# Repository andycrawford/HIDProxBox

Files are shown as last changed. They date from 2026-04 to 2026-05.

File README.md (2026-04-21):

# HIDProxBox

A 4-port Bluetooth/USB HID KVM proxy built on a Raspberry Pi and four CH552T microcontrollers. HIDProxBox sits between your input devices (a physical USB keyboard or a Bluetooth keyboard) and up to four computers, letting you switch between hosts instantly with a button press — no software installation required on any of the target computers.

---

## What It Does

- **Switch between 4 computers** with dedicated selector buttons — all computers stay USB-connected at all times
- **Accept input from a physical USB keyboard** plugged into the Pi, or from **any Bluetooth keyboard**
- **Toggle keyboard input source** (USB ↔ BT) with a single button
- **Output via USB** (the Pi talks to each computer through an individual CH552T HID device) **or via Bluetooth** (the Pi presents itself as a wireless keyboard directly to the selected computer)
- **Hold a button to pair** — one hold gesture pairs an upstream BT keyboard; another pairs the Pi itself as a BT keyboard to the active computer
- **LED feedback** — six indicator LEDs show which computer is active, which input source is live, and which output mode is in use
- **Web control panel** — a built-in HTTP server at `http://<pi-ip>:8080` lets you switch computers and toggle modes from any browser on your network
- **Local touchscreen display** — an optional tkinter GUI (`display.py`) runs on a Pi-attached touchscreen, mirroring the web panel with one-tap computer switching and a ZSA Keymapp launcher

---

## Table of Contents

1. [Architecture](#architecture)
2. [Hardware Bill of Materials](#hardware-bill-of-materials)
3. [Assembly & Wiring](#assembly--wiring)
   - [Overview diagram](#overview-diagram)
   - [GPIO buttons](#gpio-buttons-active-low)
   - [GPIO LEDs](#gpio-leds-active-high)
   - [CH552T units](#ch552t-units-one-per-computer)
4. [Software Installation](#software-installation)
5. [CH552T Firmware](#ch552t-firmware)
6. [Configuration](#configuration)
7. [Running the Daemon](#running-the-daemon)
8. [Web Control Panel](#web-control-panel)
   - [Paste Text Entry](#paste-text-entry)
9. [Local Touchscreen Display](#local-touchscreen-display)
10. [Operation](#operation)
11. [HID Macros](#hid-macros)
12. [Troubleshooting](#troubleshooting)
13. [Project Structure](#project-structure)
14. [Contributing](#contributing)
15. [License](#license)

---

## Architecture

```
┌─────────────────────────────────────────────────────────────────┐
│                        Raspberry Pi                             │
│                                                                 │
│  ┌────────────┐   ┌───────────┐   ┌──────────────────────────┐ │
│  │ usb_kbd.py │   │bt_listener│   │      gpio_watcher.py     │ │
│  │ (evdev)    │   │   .py     │   │ 4× computer select btns  │ │
│  │ USB kbd in │   │ BT kbd in │   │ BT-input btn (s/l press) │ │
│  └─────┬──────┘   └─────┬─────┘   │ BT-output btn(s/l press)│ │
│        │  source="usb"  │  source="bt"   └──────┬───────────┘ │
│        └────────────────┴────────────────────────┤             │
│                                                   ▼             │
│                              ┌────────────────────────────┐    │
│                              │         router.py          │    │
│                              │  active_computer : 1–4     │    │
│                              │  input_mode : usb | bt     │    │
│                              │  output_mode: usb | bt     │    │
│                              └──────────┬─────────────────┘    │
│                                         │                       │
│                    ┌────────────────────┴──────────────────┐   │
│                    ▼  output_mode=usb                       ▼   │
│          ┌─────────────────┐                  ┌─────────────────┐│
│          │  hid_writer.py  │                  │  bt_output.py   ││
│          │ 4× serial ports │                  │ Pi as BT HID    ││
│          └──┬──┬──┬──┬─────┘                  │ keyboard device ││
│             │  │  │  │                         └────────┬────────┘│
└─────────────┼──┼──┼──┼──────────────────────────────────┼────────┘
              │  │  │  │  /dev/ttyUSB0–3                   │ Bluetooth
       ┌──────┘  │  │  └──────┐                            │
       ▼         ▼  ▼         ▼                            ▼
  ┌────────┐ ┌──────┐ ┌──────┐ ┌────────┐        (selected computer)
  │CH552T 1│ │  #2  │ │  #3  │ │CH552T 4│
  │USB HID │ │      │ │      │ │USB HID │
  └───┬────┘ └──┬───┘ └──┬───┘ └───┬────┘
      │         │         │         │  USB cables (always plugged in)
      ▼         ▼         ▼         ▼
  Computer1  Computer2  Computer3  Computer4
```

The daemon also starts a **web UI** thread (`web_ui.py`) that serves a browser-based control panel. The optional **display** process (`display.py`) connects to this same HTTP API over localhost.

### File Overview

| File | Role |
|---|---|
| `config.py` | Single source of truth — serial ports, GPIO pins, button actions, LED pins, BT settings |
| `router.py` | Central state machine; drains the shared report queue and dispatches to the right output sink |
| `usb_kbd.py` | Reads a physical USB keyboard via evdev; converts Linux key events to 8-byte HID reports |
| `bt_listener.py` | Bluetooth HID host — receives HID reports from a paired BT keyboard |
| `bt_output.py` | Bluetooth HID device — makes the Pi appear as a wireless keyboard to computers |
| `hid_writer.py` | USB output sink — manages four CH552T serial connections, routes reports to the active one |
| `gpio_watcher.py` | Button input with short/long press detection; drives all six indicator LEDs |
| `web_ui.py` | Lightweight HTTP control panel — serves a browser UI and a JSON status/control API |
| `display.py` | Optional local touchscreen GUI — polls web_ui and drives a tkinter interface |
| `daemon.py` | Entry point — wires all subsystems, installs signal handlers, runs the health watchdog |
| `gadget_setup.sh` | Optional: configures Linux USB gadget mode (keyboard + mouse on /dev/hidg0/1) |
| `firmware/ch552t_hid_proxy/ch552t_hid_proxy.ino` | Arduino sketch for each CH552T unit |

---

## Hardware Bill of Materials

| Qty | Item | Notes |
|-----|---|---|
| 1 | Raspberry Pi Zero 2W **or** Pi 4 | Pi 4 preferred — multiple hardware UARTs, more USB ports |
| 4 | CH552T microcontroller (breakout or bare chip) | [Available on LCSC](https://lcsc.com/search?q=CH552T) |
| 4 | USB-serial adapter (CP2102 / CH340) | One per CH552T; provides /dev/ttyUSB0–3 |
| 4 | USB-A to USB-C (or USB-B) cable | One per computer — always stay plugged in |
| 6 | Momentary push-buttons (SPST NO) | Active-low; any 6 mm tactile switch works |
| 6 | LEDs (any color) + 220 Ω resistors | Indicator LEDs; one per button |
| 2 | LEDs per CH552T + 220 Ω resistors | Active LED (P3.4) and optional status LED (P1.4) per unit |
| — | 22 Ω resistors × 8 | USB D+/D− series resistors (2 per CH552T unit) |
| — | 3.3 V power rail | CH552T is a 3.3 V part; USB-serial adapters typically provide 3.3 V |
| — | Enclosure of your choice | |
| 1 | 3.5–7″ Pi-compatible touchscreen (optional) | For `display.py` local GUI |

---

## Assembly & Wiring

### Overview Diagram

The diagram below shows the full assembly at a glance. Each CH552T lives between the Pi (via a USB-serial adapter) and one target computer (via USB). All button/LED wiring is direct GPIO.

```
                        ╔═══════════════════════════════╗
                        ║         Raspberry Pi          ║
                        ║                               ║
  USB kbd ──────────────║─ USB-A                        ║
                        ║                               ║
  BT kbd (wireless) ────║─ hci0 (onboard BT)            ║
                        ║                               ║
  Buttons ─────────────►║ BCM 4,17,27,22 (computers)   ║
  (to GND)              ║ BCM 5 (BT input)              ║
                        ║ BCM 6 (BT output)             ║
                        ║                               ║
  LEDs ◄────────────────║ BCM 12,16,20,21 (computers)   ║
  (to GND via 220Ω)     ║ BCM 24 (BT input active)      ║
                        ║ BCM 25 (BT output active)     ║
                        ║                               ║
                        ║ USB ports:                    ║
                        ║  /dev/ttyUSB0 ─────────►──────║──► CH552T #1 ──USB──► Computer 1
                        ║  /dev/ttyUSB1 ─────────►──────║──► CH552T #2 ──USB──► Computer 2
                        ║  /dev/ttyUSB2 ─────────►──────║──► CH552T #3 ──USB──► Computer 3
                        ║  /dev/ttyUSB3 ─────────►──────║──► CH552T #4 ──USB──► Computer 4
                        ║                               ║
                        ║ Touchscreen (optional):        ║
                        ║  DSI / HDMI ──► display.py    ║
                        ╚═══════════════════════════════╝
```

---

### GPIO Buttons (active-low)

Each button connects between a BCM GPIO pin and GND. The Pi's internal pull-up holds the pin HIGH at rest; pressing pulls it LOW.

```
  Pi BCM pin ──┬── Button ── GND
               │
            (pull-up)
```

| BCM Pin | Button Function | Short Press | Long Press |
|---|---|---|---|
| 4 | Computer 1 | Select computer 1 | Select computer 1 |
| 17 | Computer 2 | Select computer 2 | Select computer 2 |
| 27 | Computer 3 | Select computer 3 | Select computer 3 |
| 22 | Computer 4 | Select computer 4 | Select computer 4 |
| 5 | BT keyboard | Toggle USB ↔ BT input | Pair BT keyboard to Pi |
| 6 | BT output | Toggle USB ↔ BT output | Pair Pi as BT keyboard to active computer |

---

### GPIO LEDs (active-high)

Each LED connects from a BCM pin through a 220 Ω current-limiting resistor to the LED anode, with the cathode to GND.

```
  Pi BCM pin ──── 220 Ω ──── LED (+) ──── LED (−) ──── GND
```

| BCM Pin | Indicator |
|---|---|
| 12 | Computer 1 active |
| 16 | Computer 2 active |
| 20 | Computer 3 active |
| 21 | Computer 4 active |
| 24 | BT keyboard input active |
| 25 | BT output mode active |

---

### CH552T Units (one per computer)

Each CH552T unit needs:
- **UART** from a CP2102/CH340 USB-serial adapter on the Pi (TX/RX/GND/3V3)
- **USB D+/D−** to the target computer (with 22 Ω series resistors)
- **Two optional LEDs** for active and status indication

**Single CH552T wiring (repeat × 4, incrementing ttyUSB number):**

```
┌──────────────────────────────────────────────────────────────┐
│                       CH552T Unit #1                         │
│                                                              │
│  Pi /dev/ttyUSB0 TX  ──────────  P3.0 (RXD1)               │
│  Pi /dev/ttyUSB0 RX  ──────────  P3.1 (TXD1)               │
│  Pi GND              ──────────  GND                        │
│  Pi 3.3V             ──────────  VCC                        │
│                                                              │
│  P3.4 ──── 220 Ω ──── ACTIVE LED (+) ──── LED (−) ──── GND │
│            (solid on = computer selected; off = standby)     │
│                                                              │
│  P1.4 ──── 220 Ω ──── STATUS LED (+) ──── LED (−) ──── GND │
│            (blinks on valid frame; double-blink on error)    │
│                                                              │
│  USB D+  ──── 22 Ω ──────────── Computer 1 USB D+          │
│  USB D−  ──── 22 Ω ──────────── Computer 1 USB D−          │
│  GND     ──────────────────────  Computer 1 USB GND         │
│  VBUS    ──────────────────────  Computer 1 USB VBUS (5V)   │
│                          (VBUS is for detection only —       │
│                           CH552T is powered from Pi 3.3V)   │
└──────────────────────────────────────────────────────────────┘
```

Repeat the above for units #2–#4, substituting `/dev/ttyUSB1`, `ttyUSB2`, `ttyUSB3` and `Computer 2`–`4`.

> **Voltage note:** CH552T is a 3.3 V part. The Raspberry Pi GPIO pins and USB-serial adapters operating at 3.3 V need no level shifter. **Do not connect a 5 V UART directly.**

#### CH552T LED Behavior Summary

| LED | Pin | Behavior |
|-----|-----|---|
| Active LED | P3.4 (active-low) | Solid ON = this computer is the selected KVM target; OFF = standby |
| Status LED | P1.4 (active-low, optional) | Single blink = valid frame received; double-blink = checksum error |

On power-up the firmware blinks the active LED three times to confirm it is running.

---

## Software Installation

### 1. Prepare the Raspberry Pi

Flash Raspberry Pi OS Lite (64-bit) and complete initial setup, then:

```bash
# Update system packages
sudo apt update && sudo apt upgrade -y

# System dependencies
sudo apt install -y \
  python3-pip python3-dbus python3-gi python3-tk \
  bluez bluetooth \
  wmctrl   # optional — needed for Keymapp window focus in display.py

# Python dependencies
pip3 install evdev pyserial pybluez --break-system-packages
```

### 2. Enable required kernel modules (USB gadget mode — optional)

If you want the Pi itself to appear as a USB HID device (`gadget_setup.sh`), add to `/boot/firmware/config.txt` (path may be `/boot/config.txt` on older images):

```ini
dtoverlay=dwc2
enable_uart=1
```

Add to `/etc/modules`:

```
dwc2
libcomposite
```

> **Skip this step** if you only use the CH552T USB output path or Bluetooth output. USB gadget mode is an additional, optional output path.

### 3. Clone HIDProxBox

```bash
git clone https://github.com/andycrawford/HIDProxBox.git /opt/hidproxbox
cd /opt/hidproxbox
chmod +x gadget_setup.sh
```

### 4. Create required runtime directories

```bash
sudo mkdir -p /var/lib/hidproxbox   # BT pairing state
sudo mkdir -p /var/log              # log file (usually exists)
```

### 5. Configure

Edit `/opt/hidproxbox/config.py` to match your hardware (see [Configuration](#configuration)).

### 6. Flash CH552T firmware

See [CH552T Firmware](#ch552t-firmware) below.

### 7. Install and start the systemd service

```bash
sudo cp /opt/hidproxbox/hidproxbox.service /etc/systemd/system/
sudo systemctl daemon-reload
sudo systemctl enable hidproxbox
sudo systemctl start hidproxbox
sudo systemctl status hidproxbox
```

**Example `/etc/systemd/system/hidproxbox.service`:**

```ini
[Unit]
Description=HIDProxBox KVM Daemon
After=network.target bluetooth.target

[Service]
Type=simple
ExecStartPre=/usr/bin/bash /opt/hidproxbox/gadget_setup.sh up
ExecStart=/usr/bin/python3 /opt/hidproxbox/daemon.py --foreground
ExecStopPost=/usr/bin/bash /opt/hidproxbox/gadget_setup.sh down
Restart=on-failure
RestartSec=5

[Install]
WantedBy=multi-user.target
```

> Remove the `ExecStartPre` / `ExecStopPost` lines if you are not using USB gadget mode.

---

## CH552T Firmware

Each of the four CH552T units runs the same Arduino sketch. Flash each one individually before wiring them into the system.

### Install ch55xduino in Arduino IDE

1. Open Arduino IDE → **File → Preferences**
2. Add this URL to *Additional boards manager URLs*:
   ```
   https://raw.githubusercontent.com/DeqingSun/ch55xduino/master/package_ch55xduino_mcs51_index.json
   ```
3. **Tools → Board → Boards Manager**, search `ch55x`, install **ch55xduino**.

### Board settings

| Setting | Value |
|---|---|
| Tools → Board | CH55x boards → **CH552** |
| Tools → Clock Source | **16 MHz (internal)** |
| Tools → Upload Method | **USB (bootloader)** |
| Tools → USB Settings | **USER CODE w/ 148B USB ram** |

### Enter bootloader mode

For a **bare CH552T chip**, hold the BOOT pin (P3.6) LOW while applying power, then release — the chip enumerates as a bootloader device.

For a **CH552T on a breakout board**, there is typically a BOOT button — hold it while plugging in USB, then release.

### Upload

Open `firmware/ch552t_hid_proxy/ch552t_hid_proxy.ino` and click **Upload**. Repeat for each of the four units. All four units use identical firmware; they are distinguished only by which serial port and computer they are physically wired to.

### Verify

After flashing and reconnecting to the computer's USB port, the active LED (P3.4) blinks three times to confirm the firmware is running. Check Device Manager (Windows) or `lsusb` (Linux/macOS) to confirm the CH552T enumerates as a USB HID keyboard/mouse.

### Serial Frame Protocol (reference)

The Pi speaks a simple framed binary protocol to each CH552T over UART at 115200 baud:

```
[0xAA] [TYPE] [LEN] [DATA × LEN bytes] [CHECKSUM]

CHECKSUM = XOR of TYPE ^ LEN ^ DATA[0] ^ … ^ DATA[N-1]
```

| TYPE | LEN | Payload |
|---|-----|---|
| `0x01` | 8 | Keyboard: `[modifier, 0x00, key1..key6]` |
| `0x02` | 4 | Mouse: `[buttons, X, Y, wheel]` (signed int8) |
| `0x03` | 2 | Consumer (multimedia): `[usage_lo, usage_hi]` |
| `0x10` | 1 | Set-active LED: `0x01`=on, `0x00`=off |
| `0xFE` | 0 | Ping (no-op) |
| `0xFF` | 0 | Reset — release all keys/buttons |

---

## Configuration

Edit `/opt/hidproxbox/config.py`. Every tuneable parameter is documented inline. Key sections:

### Serial ports

```python
COMPUTERS: Dict[int, str] = {
    1: "/dev/ttyUSB0",
    2: "/dev/ttyUSB1",
    3: "/dev/ttyUSB2",
    4: "/dev/ttyUSB3",
}
```

Check which `ttyUSB*` node each adapter claims after plugging them in:

```bash
dmesg | grep ttyUSB
# or
ls -l /dev/ttyUSB*
```

For persistent naming regardless of plug-in order, create udev rules (see Troubleshooting).

### Bluetooth input

```python
BT_DEVICE_MAC   = ""   # "" = accept any paired BT keyboard; or set "AA:BB:CC:DD:EE:FF"
BT_AUTO_RECONNECT = True
BT_RECONNECT_DELAY = 5  # seconds between reconnect attempts
```

### Bluetooth output

```python
BT_OUTPUT_DEVICE_NAME = "HIDProxBox"  # name advertised when pairing
BT_PAIRING_TIMEOUT    = 60            # seconds discoverable while waiting to pair
BT_OUTPUT_PAIRS_FILE  = "/var/lib/hidproxbox/bt_output_pairs.json"
```

Paired computer MACs are saved in `BT_OUTPUT_PAIRS_FILE` so reconnect survives reboots.

### GPIO

```python
LONG_PRESS_S  = 1.5   # seconds held to trigger long-press action
GPIO_BOUNCE_MS = 50   # debounce window
```

### Web UI

```python
WEB_UI_ENABLED = True
WEB_UI_HOST    = "0.0.0.0"   # bind all interfaces; "127.0.0.1" for local-only
WEB_UI_PORT    = 8080
```

### Local display

```python
DISPLAY_ENABLED    = True
DISPLAY_FULLSCREEN = False   # True = kiosk/fullscreen mode
DISPLAY_WIDTH      = 480     # window width when not fullscreen
DISPLAY_HEIGHT     = 320     # window height when not fullscreen
DISPLAY_POLL_MS    = 250     # web_ui polling interval

KEYMAPP_CMD        = "keymapp"   # path to ZSA Keymapp binary
KEYMAPP_WINDOW_NAME = "Keymapp"  # window title for wmctrl/xdotool focus
```

### Logging

```python
LOG_LEVEL       = "INFO"
LOG_FILE        = "/var/log/hidproxbox.log"
LOG_MAX_BYTES   = 5 * 1024 * 1024   # rotate at 5 MB
LOG_BACKUP_COUNT = 3
```

---

## Running the Daemon

```bash
# Foreground (logs to stderr — useful when testing)
sudo python3 /opt/hidproxbox/daemon.py --foreground

# Background (writes to LOG_FILE)
sudo python3 /opt/hidproxbox/daemon.py

# Via systemd
sudo systemctl start hidproxbox
sudo systemctl status hidproxbox
sudo journalctl -u hidproxbox -f
```

The daemon starts these threads in order: Router → BTOutput → BTListener → USBKeyboard → GPIOWatcher → WebUI. The watchdog loop restarts the Router thread automatically if it ever dies.

---

## Web Control Panel

When `WEB_UI_ENABLED = True`, the daemon starts a built-in HTTP server at:

```
http://<pi-ip-address>:8080/
```

Open this URL in any browser on your local network to get a dark-themed control panel.

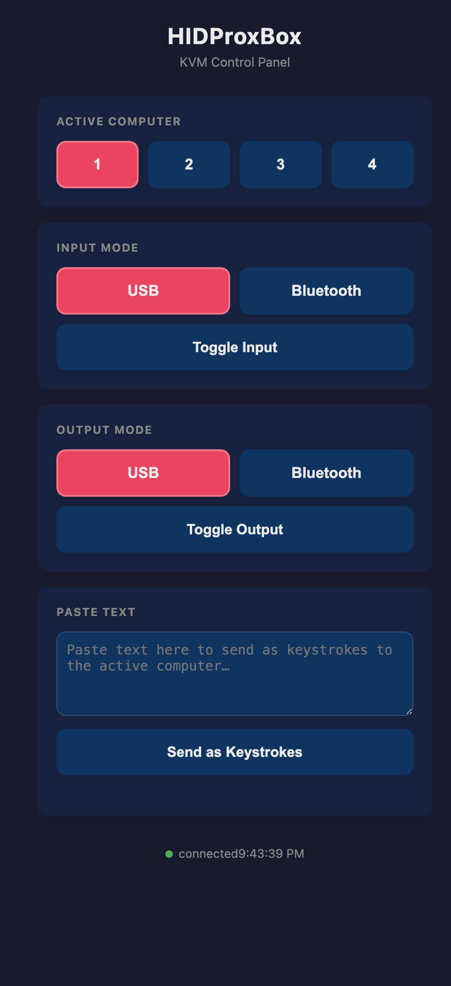
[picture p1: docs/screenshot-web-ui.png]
HIDProxBox web control panel


### Endpoints

| Method | Path | Description |
|---|---|---|
| `GET` | `/` | HTML control panel |
| `GET` | `/api/status` | JSON: `{active_computer, input_mode, output_mode}` |
| `POST` | `/api/computer/<1–4>` | Select computer *n*; returns updated status JSON |
| `POST` | `/api/input/toggle` | Toggle USB ↔ BT input; returns updated status JSON |
| `POST` | `/api/output/toggle` | Toggle USB ↔ BT output; returns updated status JSON |
| `POST` | `/api/paste` | Type arbitrary text on the active computer; body: `{"text": "..."}` (max 2000 chars); returns `{"sent": N, "skipped": N}` |

The HTML panel polls `/api/status` every second and highlights the active computer and mode buttons. A connection indicator turns red when the daemon cannot be reached.

### Paste Text Entry

The web control panel includes a **Paste Text** card that lets you type or paste any text into a browser text area and send it as keystrokes to the active computer — no clipboard sharing or remote agent required.

**How it works:**

1. Open the control panel at `http://<pi-ip>:8080/`
2. Scroll to the **Paste Text** card
3. Type or paste the text you want to send into the text area (up to 2,000 characters)
4. Click **Send as Keystrokes** — the daemon replays the text character by character as USB or Bluetooth HID keyboard events on the active computer

The panel reports how many characters were sent and how many were skipped. Characters outside the standard US ANSI printable set (letters, digits, punctuation, whitespace, Enter) are skipped and counted in the `skipped` field.

**Common use cases:**

- Entering long, complex passwords on a machine where clipboard paste is unavailable (BIOS screens, full-disk encryption prompts, VMs with isolated clipboards)
- Pushing a one-time setup command to a headless server during initial provisioning
- Sending the same text to multiple computers in sequence by switching computers between sends

**API usage:**

```bash
# Type "hello world" followed by Enter on the active computer
curl -s -X POST http://<pi-ip>:8080/api/paste \
  -H "Content-Type: application/json" \
  -d '{"text": "hello world\n"}'
# → {"sent": 12, "skipped": 0}
```

On error the endpoint returns `{"error": "text too long (max 2000 chars)"}` with HTTP 400.

> **Security note:** The web UI has no authentication. Bind to `127.0.0.1` in `config.py` if you want to prevent network access.

---

## Local Touchscreen Display

`display.py` is an optional standalone process that runs a tkinter GUI on a Pi-attached display (HDMI, DSI, or official touchscreen). It communicates with the daemon exclusively through the web UI HTTP API — it does not link against any daemon code directly.

**Hardware target:** 3.5–7″ Pi-compatible touchscreen at 480×320 or larger.

### Start the display

```bash
# Windowed (uses DISPLAY_WIDTH / DISPLAY_HEIGHT from config.py)
python3 /opt/hidproxbox/display.py

# Kiosk / fullscreen mode
python3 /opt/hidproxbox/display.py --fullscreen

# Press Escape to exit fullscreen
```

### What the display shows

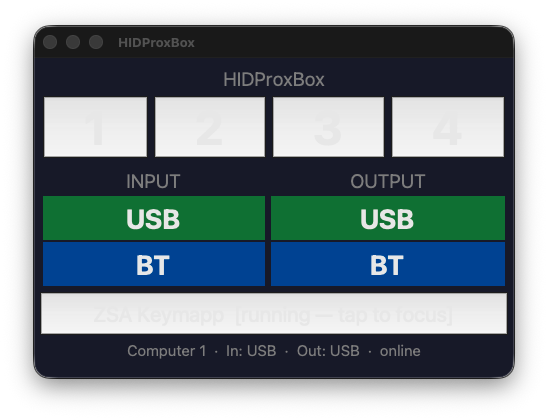
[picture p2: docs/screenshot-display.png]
HIDProxBox local display


| Region | Content |
|---|---|
| Row 1 — Tally buttons | Buttons 1–4; the active computer's button lights red. Tap to switch. |
| Row 2 — Input | USB / BT labels; the active source is highlighted green (USB) or blue (BT). |
| Row 2 — Output | USB / BT labels; the active output is highlighted green (USB) or blue (BT). |
| Row 3 — Keymapp | Purple button; tap to launch ZSA Keymapp (or focus its window if already running). |
| Status bar | Shows active computer + modes + online/offline state. |

### Autostart the display on boot (optional)

Create a systemd user service or add to `/etc/xdg/autostart/`. For a dedicated kiosk Pi:

```ini
# /etc/systemd/system/hidproxbox-display.service
[Unit]
Description=HIDProxBox Local Display
After=hidproxbox.service graphical.target
Requires=hidproxbox.service

[Service]
Type=simple
Environment=DISPLAY=:0
ExecStart=/usr/bin/python3 /opt/hidproxbox/display.py --fullscreen
Restart=on-failure
RestartSec=3

[Install]
WantedBy=graphical.target
```

### ZSA Keymapp integration

If you use a ZSA keyboard (Moonlander, Ergodox EZ, Planck EZ), install [Keymapp](https://www.zsa.io/flash/) on the Pi. Set `KEYMAPP_CMD` in `config.py` to the binary path. The display's Keymapp button:

- **Tap when Keymapp is not running** → launches it
- **Tap when Keymapp is running** → focuses its window (requires `wmctrl` or `xdotool`)

Install window-management helpers:

```bash
sudo apt install -y wmctrl
# or
sudo apt install -y xdotool
```

---

## Operation

### Switching computers

Press the button for the target computer (BCM pins 4 / 17 / 27 / 22). The corresponding LED on the Pi lights up, and the CH552T for the newly selected computer lights its active LED. All other CH552T active LEDs go dark.

### Switching keyboard input source

| Action | Result |
|---|---|
| Short press BCM 5 | Toggles between USB keyboard and Bluetooth keyboard as the active input. The BT-input LED (BCM 24) lights when BT is active. |
| Long press BCM 5 | Puts the Pi into BT discovery mode for `BT_SCAN_TIMEOUT` seconds. Put your Bluetooth keyboard into pairing mode during this window. |

### Switching computer output mode

| Action | Result |
|---|---|
| Short press BCM 6 | Toggles output for the active computer between USB (via CH552T) and Bluetooth. The BT-output LED (BCM 25) lights when BT is active. |
| Long press BCM 6 | Puts the Pi into BT discoverable/pairable mode for `BT_PAIRING_TIMEOUT` seconds. On the target computer, open Bluetooth settings, find **HIDProxBox**, and complete the pairing. The computer's MAC is stored and associated with the currently selected computer slot. Subsequent output-mode switches to BT will reconnect automatically. |

### Pairing summary

| Goal | Steps |
|---|---|
| Pair a BT keyboard as input | **Long press** BCM 5 → put keyboard into pairing mode within `BT_SCAN_TIMEOUT` s |
| Use BT keyboard as input | **Short press** BCM 5 (toggles to BT input mode) |
| Pair Pi as BT keyboard to a computer | Select the target computer (BCM 4/17/27/22) → **Long press** BCM 6 → pair from the computer's BT settings within `BT_PAIRING_TIMEOUT` s |
| Switch that computer to BT output | **Short press** BCM 6 (toggles to BT output mode) |
| Switch back to USB output | **Short press** BCM 6 again |

---

## HID Macros

`config.py` defines a `MACROS` dictionary of named keystroke sequences. These are available for dispatch from GPIO button actions.

Default macros (all use modifier byte, reserved, keycode format):

| Macro name | Keys |
|---|---|
| `macro_copy` | Ctrl+C |
| `macro_paste` | Ctrl+V |
| `macro_undo` | Ctrl+Z |
| `macro_save` | Ctrl+S |
| `macro_lock_screen` | GUI+L |
| `macro_screenshot` | Print Screen |

To add a macro, append an entry to `MACROS` and reference its name in `BUTTON_MAP`:

```python
MACROS["macro_sleep"] = [bytes([0x08, 0x00, 0x48, 0, 0, 0, 0, 0])]  # GUI+Power

BUTTON_MAP[26] = {"short": "macro_sleep", "long": "macro_lock_screen"}
```

HID keycodes follow the [USB HID Usage Tables](https://usb.org/document-library/hid-usage-tables-16). Modifier byte: `Ctrl=0x01`, `Shift=0x02`, `Alt=0x04`, `GUI=0x08` (left-side; right-side add 0x10 each).

Timing between keystrokes is controlled by `MACRO_KEY_HOLD_S` (default 50 ms) and `MACRO_KEY_GAP_S` (default 20 ms).

---

## Troubleshooting

### CH552T not appearing as `/dev/ttyUSB*`

```bash
dmesg | grep -E "USB|tty"
lsusb
```

- Ensure the USB-serial adapter driver is loaded: `modprobe cp210x` (CP2102) or `modprobe ch341` (CH340).
- Try a different USB port or cable.

### Persistent `/dev/ttyUSB*` naming

By default, the OS assigns `ttyUSB0–3` by plug-in order. For stable naming, create a udev rule that matches each adapter by serial number:

```bash
# Find serial numbers
udevadm info -a -n /dev/ttyUSB0 | grep '{serial}'
```

Then in `/etc/udev/rules.d/99-hidproxbox.rules`:

```
SUBSYSTEM=="tty", ATTRS{idVendor}=="10c4", ATTRS{idProduct}=="ea60", ATTRS{serial}=="XXXXXXXX", SYMLINK+="hidprox1"
```

Update `config.py` to use `/dev/hidprox1` etc.

### Bluetooth keyboard won't pair

1. Ensure `bluetoothd` is running: `sudo systemctl status bluetooth`
2. Verify `BT_INPUT_ENABLED = True` in `config.py`
3. Long-press BCM 5 to start discovery, then immediately put the keyboard into pairing mode
4. Check logs: `sudo journalctl -u hidproxbox -f`

### Web UI not reachable

- Check the daemon is running: `sudo systemctl status hidproxbox`
- Confirm `WEB_UI_ENABLED = True` and `WEB_UI_HOST = "0.0.0.0"` in `config.py`
- Check if another process is using port 8080: `ss -tlnp | grep 8080`
- Try from the Pi itself: `curl http://localhost:8080/api/status`

### Display shows "daemon offline"

`display.py` polls `http://localhost:WEB_UI_PORT/api/status`. If the daemon's web UI is not reachable, the status bar shows the offline warning. Verify the daemon is running and `WEB_UI_PORT` in `config.py` matches what `display.py` sees.

### Keys are dropped or duplicated

- Increase `REPORT_QUEUE_SIZE` in `config.py` if the queue is filling up (watch logs for warnings)
- Verify `SERIAL_BAUD = 115200` on both sides (firmware and config)
- Check for checksum errors: the status LED on each CH552T double-blinks on a bad frame

### GPIO buttons not responding

- Confirm `GPIO_ENABLED = True` in `config.py`
- Verify the button is wired between the BCM pin and GND (not 3.3V)
- Increase `GPIO_BOUNCE_MS` if you see double-triggers
- Run `gpio readall` (if `wiringpi` installed) or check with a multimeter

---

## Logs

```bash
# Live log tail
sudo tail -f /var/log/hidproxbox.log

# Or via journalctl if running as a systemd service
sudo journalctl -u hidproxbox -f

# Change log verbosity in config.py
LOG_LEVEL = "DEBUG"   # or "INFO", "WARNING", "ERROR"
```

The log file rotates at 5 MB (up to 3 backups) by default.

---

## Project Structure

```
HIDProxBox/
├── config.py                          # All hardware and behaviour settings
├── router.py                          # Central state machine + report dispatch
├── daemon.py                          # Entry point, wires all subsystems
├── hid_writer.py                      # USB output: 4× CH552T serial sink
├── bt_listener.py                     # BT input: Pi as BT HID host
├── bt_output.py                       # BT output: Pi as BT HID keyboard device
├── usb_kbd.py                         # USB input: evdev keyboard reader
├── gpio_watcher.py                    # Button handling + LED feedback
├── web_ui.py                          # HTTP control panel (port 8080)
├── display.py                         # Optional local touchscreen GUI
├── gadget_setup.sh                    # (Optional) Linux USB gadget setup
└── firmware/
    └── ch552t_hid_proxy/
        └── ch552t_hid_proxy.ino       # CH552T Arduino firmware (same for all 4)
```

---

## Contributing

Issues and pull requests are welcome.

**Adding a new input source:** create a producer thread that puts `(source_name, ReportType, bytes)` tuples onto `router.report_queue`.

**Adding a new output sink:** implement a callable accepting `(ReportType, bytes)` and register it with `router.set_usb_sink()` or `router.set_bt_sink()`.

**Adding a button action:** add a named action string to `BUTTON_MAP` in `config.py` and handle it in `gpio_watcher.py`'s dispatch method.

Keep the source/sink separation in `router.py` clean — the Router owns state and dispatch; it does not know about hardware specifics.

---

## License

MIT

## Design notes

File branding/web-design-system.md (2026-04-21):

# HIDProxBox Web Design System

> Version 1.0 · April 2026  
> Handoff spec for the Full-Stack Web Developer.  
> Source of truth for brand decisions: `branding/BRAND_GUIDE.md`

---

## Quick-start

Copy `branding/tokens.css` into the project and import it at the top of your global stylesheet. All component styles in this spec are expressed as references to those tokens.

```html
<link rel="stylesheet" href="/branding/tokens.css">
```

Apply the dark theme (default) by ensuring `<html>` has no `data-theme` attribute, or set `data-theme="dark"`. For light mode: `<html data-theme="light">`.

---

## 1. Design Tokens

All values live in `branding/tokens.css`. Below is the token inventory for quick reference.

### 1.1 Color

| Token | Dark value | Light value | Role |
|---|---|---|---|
| `--color-bg-page` | `#090D1A` | `#F8FAFC` | Page background |
| `--color-bg-surface` | `#0F172A` | `#F1F5F9` | Section / surface |
| `--color-bg-card` | `#1E293B` | `#FFFFFF` | Card / box fill |
| `--color-bg-row-alt` | `#111827` | `#F8FAFC` | Alternating table rows |
| `--color-cyan` | `#22D3EE` | `#0891B2` | Input / source / active |
| `--color-blue` | `#3B82F6` | `#2563EB` | Output / CTA / interactive |
| `--color-text-primary` | `#F1F5F9` | `#0F172A` | Primary text |
| `--color-text-muted` | `#94A3B8` | `#475569` | Secondary / body text |
| `--color-text-dim` | `#475569` | `#94A3B8` | Caption / tertiary |
| `--color-border` | `#334155` | `#E2E8F0` | Dividers, card edges |
| `--color-border-light` | `#1E293B` | `#F1F5F9` | Subtle inner borders |

**Semantic rule:** Cyan = input / source / active selection. Blue = output / destination / primary action. Never reverse these roles.

### 1.2 Typography

#### Font families

```css
--font-mono: 'JetBrains Mono', 'Fira Code', 'Courier New', monospace;
--font-sans: Inter, system-ui, -apple-system, BlinkMacSystemFont, 'Segoe UI', Helvetica, Arial, sans-serif;
```

Add these to the page `<head>` (Google Fonts or self-hosted):

```html
<link rel="preconnect" href="https://fonts.googleapis.com">
<link href="https://fonts.googleapis.com/css2?family=Inter:wght@400;500;600;700&family=JetBrains+Mono:wght@400;700&display=swap" rel="stylesheet">
```

#### Type scale

| Token | Clamp range | Use |
|---|---|---|
| `--text-hero` | 52 → 88 px | Hero wordmark, section-hero headings |
| `--text-heading` | 34 → 56 px | Section headings |
| `--text-subheading` | 20 → 30 px | Sub-sections, card group labels |
| `--text-lead` | 17 → 20 px | Introductory / hero body copy |
| `--text-body` | 15 → 17 px | Feature descriptions, prose |
| `--text-caption` | 11 → 13 px | Badges, labels, footnotes |
| `--text-code` | 13 → 15 px | Code snippets, terminal output |

#### Logo wordmark — three-color split

Always render the logo wordmark as three distinct spans. Never merge or recolor arbitrarily.

```html
<!-- Dark background -->
<span class="font-mono font-bold" style="color:#22D3EE">HID</span>
<span class="font-mono font-bold" style="color:#F1F5F9">Prox</span>
<span class="font-mono font-bold" style="color:#3B82F6">Box</span>

<!-- Light background — swap to higher-contrast variants -->
<span class="font-mono font-bold" style="color:#0891B2">HID</span>
<span class="font-mono font-bold" style="color:#0F172A">Prox</span>
<span class="font-mono font-bold" style="color:#2563EB">Box</span>
```

#### Section heading anatomy

```
[36–56 px bold] Section title          → --color-text-primary
[15–17 px reg]  One-line sub-title     → --color-text-dim
```

Top margin above section title: `var(--section-py)` (60–120 px).  
Bottom margin before first component: 40–56 px.

### 1.3 Spacing

All spacing uses an **8 px base unit**. Use tokens from `--space-1` (4 px) through `--space-32` (128 px). Do not hard-code ad-hoc pixel values — pick the nearest token.

Typical cadences:

| Context | Token |
|---|---|
| Icon ↔ label gap | `--space-2` (8 px) |
| Card internal padding | `--space-6` (24 px) |
| Card-to-card gap | `--space-5` (20 px) |
| Section side margins | `--grid-padding` (clamp 16→48 px) |
| Vertical section rhythm | `--section-py` (clamp 60→120 px) |

### 1.4 Grid

```
max-width: var(--grid-max-width)  /* 1280 px */
padding-inline: var(--grid-padding) /* clamp(16px, 4vw, 48px) */
columns: 12
gutter: var(--grid-gap)  /* 24 px */
```

Use a CSS grid layout:

```css
.grid-12 {
  display: grid;
  grid-template-columns: repeat(12, 1fr);
  gap: var(--grid-gap);
}
```

Standard column spans: hero text = 10 col (offset 1), feature cards = 3 col each, use-case cards = 4 col each, BOM table = 12 col.

---

## 2. Background Pattern

Large surfaces (hero, CTA) use the dot-grid texture:

```css
.bg-hero {
  background-color: var(--color-bg-page);
  background-image: var(--pattern-dot-grid);
}
```

The pattern is a 40×40 px SVG tile with a single `0.8 px` circle at center, color `#1E2D45`, opacity `0.85`. On light mode the dot color switches to `#CBD5E1` at `0.6` opacity (see `tokens.css`).

Circuit trace accents (thin 90° polylines with endpoint dots) may be applied at page corners for texture. Color: `#1E2D45`, stroke-width `1.5`, opacity `0.7`. Keep them clearly subordinate to content.

---

## 3. Component Library

### 3.1 Navigation Bar

**Mockup:** `branding/mockup-hero.svg` (top 60 px)

```
Height:           60 px
Background:       --color-bg-page at 96% opacity (allows blur/glass effect)
Border-bottom:    1px solid --color-border at 60% opacity
Logo:             branding/logo-dark.svg at ~43 px height, 16px left margin
Nav links:        --font-sans 14px · --color-text-muted · 28px right gap
CTA button:       btn--primary · 34px height · 16px px
Position:         sticky top-0, z-index 50
```

```html
<nav class="navbar">
  <img src="/branding/logo-dark.svg" height="43" alt="HIDProxBox">
  <a href="#features">Features</a>
  <a href="#usecases">Use Cases</a>
  <a href="#bom">BOM</a>
  <a href="https://github.com/…">GitHub</a>
  <a href="#" class="btn btn--primary">Get Started</a>
</nav>
```

---

### 3.2 Hero Section

**Mockup:** `branding/mockup-hero.svg`

Hero section mockup

**Layout:**
```
Background:     --color-bg-page + --pattern-dot-grid
Min height:     560 px
Content:        centered column, max-width 860 px
Vertical align: center (padding-top ~80 px below nav, padding-bottom 80 px)
```

**Content stack (top → bottom):**

```
1. Logo mark + wordmark        → branding/logo-dark.svg at 2× (128 px height)
   — font: --font-mono, 52 px, weight 700, letter-spacing -1 px
   — three-color split: HID=#22D3EE  Prox=#F1F5F9  Box=#3B82F6

2. Tagline                     → 20 px, --color-text-muted, centered
   "One keyboard. Four computers. Zero software on the targets."

3. Sub-tagline                 → 14 px, --color-text-dim, centered
   "Open-source Raspberry Pi KVM proxy — hardware-level USB and Bluetooth HID switching"

4. CTA row (gap: 16 px)
   [View on GitHub →]          → btn--primary  170×48 px  rx=8
   [Read the Docs]             → btn--ghost    150×48 px  rx=8

5. Status badges (gap: 10 px, top margin 16 px)
   • MIT License               → .badge         (dot: --color-text-dim)
   • Raspberry Pi              → .badge--blue    (dot: --color-blue)
   • 4-Port KVM                → .badge--cyan    (dot: --color-cyan)
```

---

### 3.3 Feature Grid

**Mockup:** `branding/mockup-features.svg`

Feature grid mockup

**Layout:** 4 columns on desktop, 2 columns on tablet, 1 column on mobile.

```
Background:   --color-bg-surface (Navy)
Card width:   span 3 / 12 cols (≈ 281 px at max-width)
Card height:  auto (min 148 px)
Card gap:     var(--space-5) = 20 px
Section padding: var(--section-py)
```

**Card anatomy:**

```
┌──────────────────────────────────┐  ← 3 px top accent strip (cyan or blue)
│ ● Title text                 14px │  ← leading dot 8 px · title font-weight 600
│                                   │
│   Body description           12px │  ← 2 lines · --color-text-muted
│   Second line                     │
│                                   │
│   CATEGORY LABEL            11px  │  ← all-caps · --color-cyan or --color-blue
└──────────────────────────────────┘
```

**Accent rule:**
- Row 1 (Input features) → `--color-cyan` top strip + dot
- Row 2 (Output/control features) → `--color-blue` top strip + dot

```html
<!-- Input card -->
<div class="card card--cyan">
  <h3>4-Port Instant Switching</h3>
  <p>Dedicated selector buttons with LED confirmation. Zero warm-up.</p>
  <span class="text-caption" style="color:var(--color-cyan)">INPUT</span>
</div>

<!-- Output card -->
<div class="card card--blue">
  <h3>USB + Bluetooth Output</h3>
  <p>Relay via CH552T USB HID or Pi's own Bluetooth HID mode.</p>
  <span class="text-caption" style="color:var(--color-blue)">OUTPUT</span>
</div>
```

**All 8 features:**

| # | Category | Title | Body |
|---|---|---|---|
| 1 | INPUT (cyan) | 4-Port Instant Switching | Dedicated selector buttons with LED confirmation. Zero warm-up. |
| 2 | INPUT (cyan) | Wired + Wireless Input | USB keyboard via evdev or any Bluetooth HID keyboard. |
| 3 | INPUT (cyan) | Programmable Macros | Map HID keystroke sequences to button presses via `config.py`. |
| 4 | INPUT (cyan) | Zero Target Software | Each CH552T appears as a standard USB HID device — no drivers. |
| 5 | OUTPUT (blue) | USB + Bluetooth Output | Relay via CH552T HID devices or Pi's BT keyboard mode. |
| 6 | OUTPUT (blue) | Browser Control Panel | Switch computers from any phone or browser at `:8080`. |
| 7 | OUTPUT (blue) | Optional Touchscreen | Local tkinter GUI with tally lights and one-tap switching. |
| 8 | OUTPUT (blue) | Open-Source & Hackable | Producer-consumer architecture — extend in a few dozen lines. |

---

### 3.4 Use-Case Cards

**Mockup:** `branding/mockup-usecases.svg`

Use-case cards mockup

**Layout:** 3 equal columns on desktop, 1 column on mobile.

```
Background:   --color-bg-page + --pattern-dot-grid
Card width:   span 4 / 12 cols (≈ 384 px at max-width)
Card height:  auto (min 288 px)
Card gap:     var(--space-6) = 24 px
```

**Card anatomy:**

```
┌──────────────────────────────────┐  ← 4 px top accent strip
│ [Category badge]         26 px   │  ← pill: rx 4 · stroke accent color
│                                   │
│ Title line 1             17px 700 │
│ Title line 2                      │
│                                   │
│ Body paragraph           13px     │  ← 4-5 lines · --color-text-muted
│ ...                               │
│──────────────────────────────────│  ← --color-border divider
│ ● Detail callout         11px     │  ← dot in accent color
└──────────────────────────────────┘
```

**Three cards:**

| # | Accent | Badge | Title | Callout |
|---|---|---|---|---|
| 1 | Cyan | Developer | The Multi-Machine Developer | Button 1 → workstation · Button 2 → laptop (BT) |
| 2 | Blue | Home Office | The Clean-Desk Home Office | BT output → Mac stays cable-free |
| 3 | Cyan | Maker | The Maker Workbench | Touchscreen on project enclosure front panel |

---

### 3.5 BOM Table

**Mockup:** `branding/mockup-bom.svg`

BOM table mockup

**Layout:** full-width (12 cols), inside a single card container.

```
Background:   --color-bg-surface (Navy)
Container:    rx=8 · border 1px --color-border · max-width 1184 px
Header row:   h=44 px · bg=--color-bg-card · font 12px 700 letter-spacing 0.06em all-caps --color-text-muted
Data rows:    h=44 px · alternating --color-bg-surface / --color-bg-row-alt
Total row:    h=44 px · bg=--color-bg-card · cost value in --color-cyan
```

**Column widths (at 1184 px table):**

| Column | Width | Align | Notes |
|---|---|---|---|
| Component | ~71% (≈ 844 px) | Left | Leading accent dot: cyan for core, blue for USB output, dim for optional/passive |
| Qty | ~13% (≈ 152 px) | Left | Plain number or `—` |
| Approx. Cost | ~16% (≈ 188 px) | Right | Right-aligned; total cell uses `--color-cyan` |

**HTML structure:**

```html
<div class="card" style="padding:0; overflow:hidden;">
  <table style="width:100%; border-collapse:collapse;">
    <thead>
      <tr style="background:var(--color-bg-card);">
        <th>Component</th>
        <th>Qty</th>
        <th style="text-align:right">Approx. Cost</th>
      </tr>
    </thead>
    <tbody>
      <tr class="row-alt"><td>…</td>…</tr>
      <!-- alternate rows use --color-bg-row-alt -->
    </tbody>
    <tfoot>
      <tr style="background:var(--color-bg-card);">
        <td colspan="2">Total (4-port build)</td>
        <td style="color:var(--color-cyan); text-align:right; font-weight:700">under $100</td>
      </tr>
    </tfoot>
  </table>
</div>
```

**Leading dot colors:**
- Raspberry Pi → `--color-cyan` (core compute, input side)
- CH552T + USB serial → `--color-blue` (USB output side)
- Buttons / LEDs / touchscreen → `--color-text-dim` (passive / optional)

---

### 3.6 CTA + Footer

**Mockup:** `branding/mockup-cta-footer.svg`

CTA + footer mockup

**CTA section:**

```
Background:    --color-bg-page + --pattern-dot-grid + corner circuit traces
Padding:       var(--section-py) top, 80 px bottom
Content:       centered column, max-width 700 px
```

Content stack:

```
1. Pre-heading pill badge
   "Open Source · MIT License"
   → .badge · rx=13 (pill) · border --color-border · dot --color-cyan
   → margin-bottom 24 px

2. Headline          48 px  700  --color-text-primary
   "Build yours this weekend."

3. Sub-line          17 px  400  --color-text-muted
   "All firmware, all code, all wiring diagrams — in the repo."
   → margin-top 12 px

4. Button row (gap 16 px, margin-top 32 px)
   [Clone on GitHub →]  → btn--primary  190×52 px
   [Browse the Docs]    → btn--ghost    174×52 px
```

**Footer:**

```
Background:    --color-bg-page (no pattern)
Top border:    1 px solid --color-border-light
Padding:       32 px vertical
```

```
Left:    "© 2026 HIDProxBox — MIT License"    → 12 px --color-text-dim
Center:  GitHub · Docs · Firmware · Hackaday · r/raspberry_pi
         links separated by 4 px circle dots (--color-border)
Right:   "Built on Raspberry Pi" + icon mark  → 12 px --color-border
```

---

## 4. Dark / Light Mode

### Switching

The site ships dark by default. Light mode is opt-in. Toggle via:

```js
document.documentElement.dataset.theme = 'light';  // enable
delete document.documentElement.dataset.theme;      // back to dark
```

Persist the preference in `localStorage`:

```js
const saved = localStorage.getItem('theme');
if (saved) document.documentElement.dataset.theme = saved;
```

### Logo asset swap

| Context | Asset |
|---|---|
| Dark background | `branding/logo-dark.svg` |
| Light background | `branding/logo-light.svg` |

Swap with:

```js
const logo = document.querySelector('.nav-logo');
const isDark = !document.documentElement.dataset.theme;
logo.src = isDark ? '/branding/logo-dark.svg' : '/branding/logo-light.svg';
```

### Light-mode card treatment

On light mode, cards lose their dark fill and gain a `box-shadow` instead of a visible border for depth:

```css
[data-theme="light"] .card {
  background: var(--color-bg-card);   /* #FFFFFF */
  border-color: var(--color-border);  /* #E2E8F0 */
  box-shadow: var(--shadow-card);
}
```

Accent colors automatically shift to the 600-series variants via token overrides in `tokens.css`. No additional code required.

---

## 5. Badge / Pill Reference

Badges follow the brand guide pill style exactly.

```
Background:    --color-bg-card
Border:        1 px solid [accent or --color-border]
Border-radius: var(--radius-sm) = 4 px (badge) / var(--radius-full) = 9999 px (pill)
Padding:       4 px 10 px
Font:          --font-sans 12 px weight 600
Leading dot:   6 px circle in accent color
```

```html
<span class="badge">Default</span>
<span class="badge badge--cyan">Input · USB</span>
<span class="badge badge--blue">Output · BT</span>
```

---

## 6. Breakpoints

| Name | Width | Grid behaviour |
|---|---|---|
| `sm` | 640 px | 1-col layout everywhere |
| `md` | 768 px | Feature grid: 2 cols; use-case: 1 col |
| `lg` | 1024 px | Feature grid: 4 cols; use-case: 3 cols |
| `xl` | 1280 px | Full desktop layout; container hits max-width |

---

## 7. Accessibility

- All text combinations must meet WCAG AA contrast (4.5 : 1 for body, 3 : 1 for large text).
- `--color-text-muted` (#94A3B8) on `--color-bg-page` (#090D1A) = **9.4 : 1** ✓
- `--color-text-primary` (#F1F5F9) on `--color-bg-card` (#1E293B) = **10.6 : 1** ✓
- `--color-cyan` (#22D3EE) on `--color-bg-page` (#090D1A) = **9.1 : 1** ✓
- `--color-blue` (#3B82F6) on `--color-bg-page` (#090D1A) = **4.6 : 1** ✓
- Never use `--color-text-dim` (#475569) alone on `--color-bg-page` for body text — it falls below 3 : 1. Reserve for captions paired with nearby primary text.

---

## 8. Asset Inventory

| File | Purpose | Dimensions |
|---|---|---|
| `branding/tokens.css` | CSS design tokens | — |
| `branding/BRAND_GUIDE.md` | Full brand reference | — |
| `branding/icon.svg` | Favicon / avatar | 64×64 base, scalable |
| `branding/logo-dark.svg` | Logo on dark backgrounds | 252×64 |
| `branding/logo-light.svg` | Logo on light backgrounds | 252×64 |
| `branding/social-preview.svg` | GitHub social preview | 1280×640 |
| `branding/readme-banner.svg` | README header | 1280×200 |
| `branding/mockup-hero.svg` | Hero section mockup | 1280×560 |
| `branding/mockup-features.svg` | Feature grid mockup | 1280×460 |
| `branding/mockup-usecases.svg` | Use-case cards mockup | 1280×420 |
| `branding/mockup-bom.svg` | BOM table mockup | 1280×400 |
| `branding/mockup-cta-footer.svg` | CTA + footer mockup | 1280×320 |

---

*This design system is the handoff spec from the Brand Designer to the Full-Stack Web Developer. If a component detail is unclear, refer to the corresponding SVG mockup file for the ground truth visual.*

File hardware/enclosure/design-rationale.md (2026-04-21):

# HIDProxBox Enclosure Design Rationale — DVI-38

Two form factors: enhanced desktop slab and compact handheld.

---

## Desktop v2 (`enclosure_desktop_v2.scad`)

**Goal:** Iterate the DVI-35 Option A slab with ergonomic, visual, and assembly improvements while preserving full hardware and mounting compatibility.

### Changes from v1

| Feature | v1 (DVI-35) | v2 (DVI-38) | Rationale |
|---|---|---|---|
| Top profile | Flat, 32 mm | 3° tilt — 24 mm front, 32 mm rear | Wedge profile puts the display at a natural upward-facing angle for desk use; reduces perceived bulk |
| Ventilation | Right side only, 5 plain slots | Both sides, 10 paired slots | Pi 4 under load can reach 70–80 °C; adding the left side roughly doubles airflow cross-section |
| Underside | Plain floor | 4× Ø12 mm rubber-foot recesses | Flat plastic slides on smooth desks; recesses locate stick-on rubber feet precisely |
| Lid | Smooth flat | Shallow logo-plate recess (45 × 14 mm) | Provides a registration pocket for a printed or cut vinyl logo badge; removable without damaging paint |
| Interior | No cable management | Clip boss near USB-C power port | Prevents the USB-C cable from pulling the power connector loose during port switching |
| Front panel | No separator | Shallow label groove between display zone and button zone | Visual cue separating the status display from the input-select controls |

### What stayed the same

- 175 × 90 mm footprint — existing mounts/brackets fit without change
- Back panel port centres (USB-A output ×4, keyboard input, USB-C power)
- Front panel display opening (73 × 22 mm), button positions, LED positions
- M3 heat-set inserts, M3 × 10 mm lid screws (×4)
- Two-piece (bottom shell + flat lid) FDM design, zero supports

### Tilt geometry note

The tilt is implemented as a hull between a 24 mm front cross-section and a 32 mm rear cross-section. The lid top surface is flat; the underside follows the tilt so the lid sits flush on the tilted rim. Boss heights vary front-to-rear to keep boss tops level with the split plane. This approach avoids non-manifold geometry and prints cleanly without supports.

---

## Handheld (`enclosure_handheld.scad`) — rev 2

**Goal:** Redesigned to comply with the DVI-39 hardware constraint spec (received 2026-04-21).
Previous rev (120 × 62 × 22 mm, 2-computer) was too large and under-specified.

### Changes from rev 1

| Feature | Rev 1 (DVI-38 initial) | Rev 2 (DVI-39 constrained) | Rationale |
|---|---|---|---|
| Footprint | 120 × 62 mm | **90 × 50 mm** | DVI-39 specifies ≤ 90 × 50 mm target |
| Height | 22 mm | **30 mm** | Extra depth needed for 4× CH552T stack + battery headroom |
| Computer support | 2 (2× CH552T) | **4** (4× CH552T) | DVI-39 §1 — system requires 4 output computers |
| Select buttons | 2× | **4×** (two paired groups) | DVI-39 §11 — minimum 4× select |
| Status LEDs | 2× (3 mm) | **4×** (3 mm, one per computer) | Per spec: "same as desktop if space allows" |
| USB-A outputs | 2 (bottom-exit) | **4 (back panel)** | 4 outputs + 1 input = 5 ports; back-exit is cleaner for 5 cables |
| Battery | None | **Placeholder void** (TBD) | DVI-39 §8 / §11 — required; chemistry/capacity unresolved |
| Display | 1.3" OLED | **Omitted** | No space at 90 × 50 mm; spec marks it optional at this form factor |

### Design decisions

#### Form factor: 90 × 50 × 30 mm

- Meets the ≤ 90 × 50 mm footprint target from DVI-39 exactly at the boundary
- 30 mm height (vs. 22 mm rev 1) provides interior clearance for Pi Zero 2W + 4× CH552T on 10 mm standoffs + battery void: floor (2.5 mm) + Pi standoffs (~8 mm) + CH552T stack (~13 mm above Pi) = ~23.5 mm stack, plus lid (2 mm) = 25.5 mm → 30 mm shell gives 4.5 mm headroom for cables
- Pi Zero 2W (65 × 30 mm) fits within 86 × 46 mm interior pocket

#### Button layout: paired groups

4 select buttons are split into two visual groups of 2 (computers 1+2 on left, 3+4 on right) with a 22 mm inter-group gap on the front face. The 2 mode buttons are centred in that gap at a lower Z height. This mirrors the logical pairing used on the desktop and makes one-thumb selection easier.

#### Port placement: back-panel exit

5 USB-A ports (4 outputs + 1 input) exit the back panel. Rationale:
- 5 cables via the bottom edge creates cable-management chaos; back-panel grouping is cleaner
- USB-C power remains on the right side (unchanged from rev 1) for one-handed power-on access

#### Battery placeholder

DVI-39 §11 defers battery chemistry and capacity to a future decision. The shell reserves interior space beside the Pi for a slim LiPo (placeholder: 18 × 38 × 7 mm). Enable `SHOW_BATTERY_VOID = true` in the SCAD to visualise the reserved volume. Final cutout geometry and PCB/connector routing TBD once the battery spec is confirmed.

#### M2.5 fasteners (retained)

M3 bosses are too large for a 50 × 90 mm shell at 2 mm walls. M2.5 heat-set inserts (OD ~4 mm) fit a 3.8 mm outer boss with 1 mm wall margin. Boss height increased to 20 mm (from 15 mm) to match the taller 30 mm shell.

#### Corner radius: 4 mm (retained)

Handheld ergonomics benefit from a more rounded profile than the desktop's 2.5 mm. 4 mm is the practical maximum that still leaves flat wall area for vent slots and port cutouts.

### Hardware assumptions per DVI-39 spec

| Component | Spec dimension | DVI-39 ref |
|---|---|---|
| Raspberry Pi Zero 2 W | 65 × 30 mm | §11 |
| CH552T breakout board | ~40 × 15 mm (4× required) | §1 |
| Select button cap | 12 mm dia (handheld; spec unspecified) | §11 |
| Battery | TBD — chemistry/capacity unresolved | §8 / §11 |
| Display | Omitted (optional per spec) | §11 |

---

## Files

| File | Description |
|---|---|
| `enclosure_desktop_v2.scad` | Enhanced desktop — parametric OpenSCAD |
| `enclosure_handheld.scad` | Handheld — parametric OpenSCAD |
| `enclosure.scad` | Original Option A (DVI-35) — preserved for reference |
| `print_notes.md` | Print settings, orientation, and BOM for all variants |
| `generate_stl.py` | STL export script (update PARTS list to include new files) |

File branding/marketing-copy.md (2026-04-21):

# HIDProxBox — Marketing Copy

---

## Tagline

> **One keyboard. Four computers. Zero software on the targets.**

*Alternate short form (social / card preview):*
> Your keyboard, everywhere — one button press at a time.

---

## Elevator Pitch

HIDProxBox is an open-source Raspberry Pi KVM proxy that routes a single keyboard and mouse to up to four computers simultaneously. Each target sees a genuine USB or Bluetooth HID device — no drivers, no agents, no software to install on anything you want to control. Press a button (or tap the web panel from your phone) and your keystrokes instantly follow.

It accepts input from a wired USB keyboard or any Bluetooth keyboard, and it can deliver that input over USB — through four dedicated CH552T microcontrollers, one per computer — or wirelessly over Bluetooth. Mix and match: type over USB to one machine, switch, and beam keystrokes wirelessly to a laptop across the room.

---

## Feature Highlights

- **4-port instant switching** — dedicated selector buttons with LED confirmation; every computer stays USB-connected at all times, with zero warm-up delay when you switch.
- **Wired or wireless input** — accept keystrokes from a physical USB keyboard *or* any Bluetooth keyboard; toggle the active source with a single button press, or long-press to pair a new wireless keyboard on the fly.
- **USB and Bluetooth output** — relay input via dedicated CH552T HID devices over USB *or* turn the Pi itself into a Bluetooth keyboard for cable-free control; per-computer output mode persists across reboots.
- **Browser-based control panel** — a built-in web UI at `http://<pi-ip>:8080` lets you switch computers and toggle input/output modes from any phone, tablet, or browser on your network, no app required.
- **Optional touchscreen display** — a local tkinter GUI (`display.py`) runs on any Pi-compatible touchscreen for at-a-glance tally lights and one-tap switching, with a built-in ZSA Keymapp launcher for ZSA keyboard users.
- **Programmable HID macros** — map keystroke sequences (lock screen, screenshot, Ctrl+C/V, custom combos) to button short- or long-press actions via a plain Python config file.
- **Nothing to install on target computers** — each CH552T enumerates as a standard USB HID keyboard and mouse; the Pi's Bluetooth output appears as a standard wireless keyboard. Your computers never know it is a proxy.
- **Fully open-source and hackable** — Python daemon with a clean producer-consumer architecture; add new input sources or output sinks in a few lines of code.

---

## Use-Case Scenarios

### The Multi-Machine Developer

You have a beefy workstation on the left, a work laptop docked to the right, and a headless server sitting in the rack underneath. You want a single ergonomic keyboard across all three — no USB unplugging, no KVM lag, no extra software on the laptop you don't own. HIDProxBox sits in the middle: press button 1 for the workstation, button 2 for the laptop (Bluetooth, so it's still on the docking station's USB ports), and hold a button to SSH macros straight into the server. Every switch is instant, every machine thinks it has a dedicated keyboard.

### The Clean-Desk Home Office

Your personal Mac sits beside your company-issued Windows PC. You've tried software KVMs — they break after updates, they need admin rights, and your company's IT policy won't allow them. HIDProxBox is purely hardware from the target computers' perspective. Both machines are always plugged in, always ready. One physical button (or a tap on the web panel from your phone) hands input from one to the other. Toggle Bluetooth output and your Mac never needs a USB cable at all.

### The Maker Workbench

You're building and flashing firmware across a Pi, an STM32 discovery board, and an x86 test machine — all headless, all needing occasional keyboard input for setup and logs. HIDProxBox lives on a shelf, wired into all three. Pair your Bluetooth mechanical keyboard as the input source so there's no cable to knock loose. Add a couple of macro buttons to automate your most-used debug commands. Connect the optional touchscreen to the front of your project enclosure for a clean, self-contained control panel. Build it once, reuse it forever.

---

## Marketing One-Pager

> *Suitable for GitHub project description, Hackaday project page, Reddit r/raspberry_pi, or Hacker News Show HN.*

---

### HIDProxBox

**One keyboard. Four computers. Zero software on the targets.**

HIDProxBox is a DIY Raspberry Pi KVM proxy that routes keyboard and mouse input to up to four computers over USB or Bluetooth — no drivers, no agents, nothing to install on the machines you control.

#### How it works

A Python daemon on the Pi sits at the centre of a thread-based producer-consumer pipeline. Input arrives from a wired USB keyboard (via Linux evdev) or any Bluetooth keyboard. The daemon's Router dispatches each HID report to the active computer through one of four CH552T microcontrollers (one per computer, each presenting as a standard USB HID device) or via Bluetooth if you prefer wireless output.

Switch targets with a physical button, a tap on the built-in web control panel (`http://<pi-ip>:8080`), or the optional local touchscreen GUI. LED indicators confirm the active computer and input/output modes at a glance.

#### Key capabilities

| Feature | Detail |
|---|---|
| Computers supported | Up to 4 |
| Input sources | USB keyboard (evdev) or Bluetooth HID |
| Output paths | USB via CH552T HID devices or Bluetooth (Pi as BT keyboard) |
| Control | Physical buttons, web browser, or optional touchscreen |
| Pairing | Long-press to pair a BT keyboard in; long-press to pair Pi out |
| Macros | Configurable HID keystroke sequences on button actions |
| Config | Single `config.py` — ports, GPIO pins, macros, timeouts |
| Footprint | Runs on Raspberry Pi Zero 2W or Pi 4 |

#### Why HIDProxBox?

Commercial KVMs only switch USB cables. Software KVMs require agents on every machine. HIDProxBox is the middle path: real hardware-level HID switching, open-source firmware, and a clean Python codebase you can extend in an afternoon.

- **No target software** — works with air-gapped machines, locked-down corporate laptops, and everything in between.
- **Dual input** — wired and wireless keyboard support in the same box; toggle with one button.
- **Dual output** — switch between USB and Bluetooth output per computer, with pairing state persisted across reboots.
- **Web + physical control** — switch from your phone when you're not at your desk.
- **Hackable by design** — add a new input source (foot pedal? stream deck?) in a few dozen lines of Python. New output sink? Same pattern.

#### Bill of materials (approx.)

| Item | Qty | Approx. cost |
|---|-----|---|
| Raspberry Pi Zero 2W or Pi 4 | 1 | $15–$55 |
| CH552T microcontrollers | 4 | < $1 each |
| USB-serial adapters (CP2102/CH340) | 4 | ~$1–$2 each |
| Tactile buttons + LEDs + resistors | — | < $5 |
| Optional Pi touchscreen (3.5–7″) | 1 | $15–$30 |

Total hardware cost: **under $100** for a full 4-port build.

#### Get started

```bash
git clone https://github.com/andycrawford/HIDProxBox.git /opt/hidproxbox
pip3 install evdev pyserial pybluez --break-system-packages
sudo python3 /opt/hidproxbox/daemon.py --foreground
```

Flash the same Arduino sketch to each CH552T, wire the buttons and LEDs to GPIO, and you're switching computers in an afternoon.

**License:** MIT — build it, fork it, sell it, improve it.

---

*HIDProxBox is an open-source project. Contributions, issues, and hardware build logs are welcome.*

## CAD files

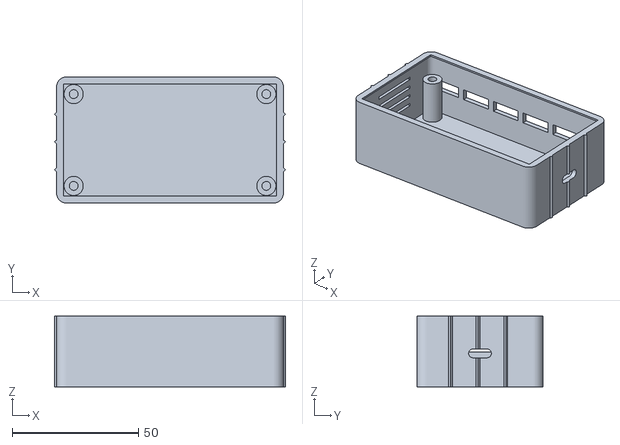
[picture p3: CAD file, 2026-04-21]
hardware/enclosure/stl/handheld_bottom.stl
91.6 x 50.0 x 28.0

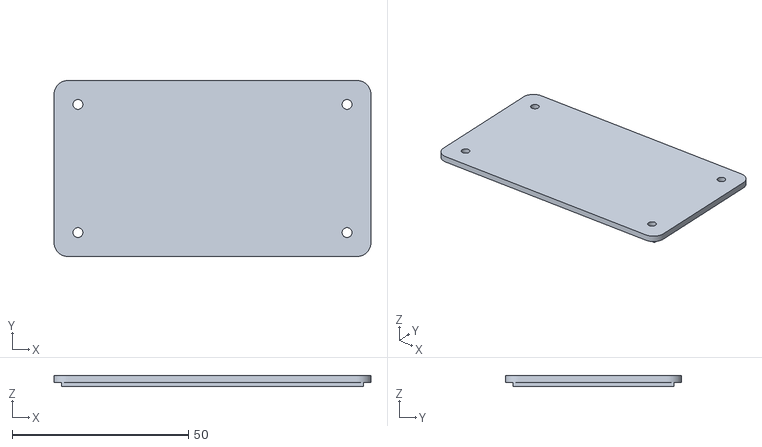
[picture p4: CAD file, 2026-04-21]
hardware/enclosure/stl/handheld_top.stl
90.0 x 50.0 x 3.20

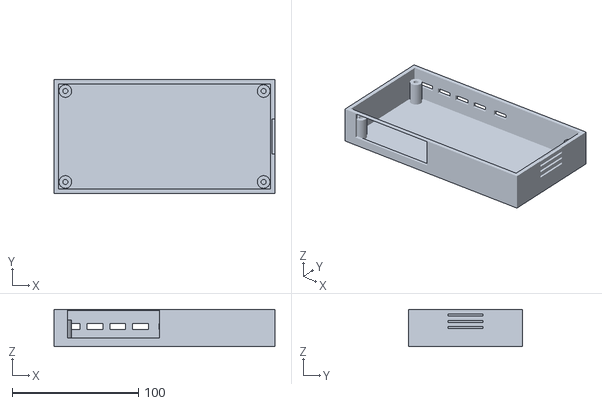
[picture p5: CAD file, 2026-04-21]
hardware/enclosure/stl/enclosure_bottom.stl
175.0 x 90.0 x 29.5

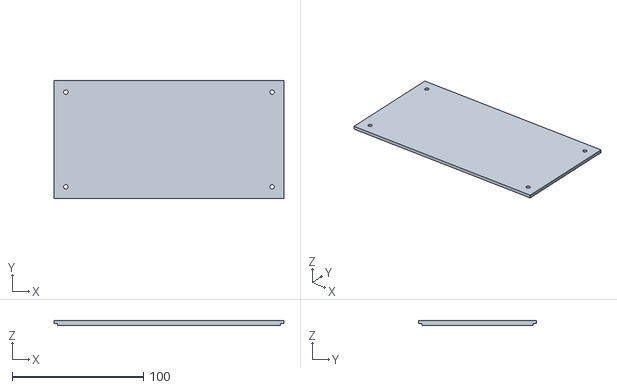
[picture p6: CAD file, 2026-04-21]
hardware/enclosure/stl/enclosure_top_lid.stl
175.0 x 90.0 x 4.00

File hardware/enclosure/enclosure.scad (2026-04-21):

/* ══════════════════════════════════════════════════════════════════════
   HIDProxBox Enclosure — Option A: Compact Slab
   Parametric OpenSCAD model · DVI-35
   Source concept: DVI-33 / branding/enclosure-a-slab.svg (commit a8979bd)

   Two-piece FDM design: bottom shell (tray) + top lid
   ── Print orientation ──────────────────────────────────────────────
   Bottom shell : floor face down, open top up.  No supports needed
                  except possible bridging for display opening (72 mm);
                  enable slicer bridging detection or add 45° chamfer
                  (already included as DISP_CHAMFER).
   Top lid      : flip 180° in slicer (outer face down, step facing up).
                  Fully flat — zero supports.
   ══════════════════════════════════════════════════════════════════════ */

/* ── MAIN DIMENSIONS (mm) ──────────────────────────────────────────── */
W  = 175;   // exterior width
D  = 90;    // exterior depth
H  = 32;    // exterior height (assembled)

/* ── WALL THICKNESS ────────────────────────────────────────────────── */
WS = 2.5;   // sides
WB = 3.0;   // base / floor
WT = 2.5;   // flat lid thickness

/* ── LID / SPLIT ───────────────────────────────────────────────────── */
LID_STEP_H  = 1.5;               // step depth below lid flat
LID_TOTAL_H = WT + LID_STEP_H;  // = 4.0 mm (printed height)
BOT_H       = H - WT;            // = 29.5 mm (bottom shell wall height)

/* ── ALIGNMENT RIB (top rim of bottom shell) ───────────────────────── */
RIB_T   = 1.0;   // rib wall thickness
RIB_H   = 0.8;   // rib protrusion above rim
FIT_GAP = 0.15;  // clearance between rib and lid groove

/* ── M3 FASTENERS ──────────────────────────────────────────────────── */
SCREW_R      = 1.65;  // M3 clearance (through-hole radius)
INSERT_R     = 2.0;   // M3 heat-set insert pocket radius
INSERT_DEPTH = 6.0;   // insert pocket depth from top of boss
BOSS_R       = 5.0;   // boss outer radius
BOSS_H       = 18.0;  // boss height from floor
BOSS_INSET   = WS + BOSS_R + 1.5;  // = 9.0 mm from outer edge

/* ── FRONT PANEL ───────────────────────────────────────────────────── */
// 3.5" display opening
DISP_X       = WS + 8.0;  // left edge from outer left (= 10.5 mm)
DISP_Z       = WB + 4.0;  // bottom from floor          (= 7.0 mm)
DISP_W       = 73.0;       // opening width
DISP_H       = 22.0;       // opening height
DISP_CHAMFER = 1.5;        // 45° chamfer on top interior edge (bridge aid)

// Right-section separator groove X position
SEP_X = DISP_X + DISP_W + 4.0;  // = 87.5 mm from left outer edge

// 4 select buttons — 16 mm diameter round caps, centered
BTN_R  = 8.0;
BTN_ZC = WB + 15.0;  // centre Z from floor  (= 18.0 mm)
BTN_XC = [SEP_X+14, SEP_X+30, SEP_X+46, SEP_X+62];  // [101.5, 117.5, 133.5, 149.5]

// 6 status LEDs — 5 mm diameter holes
LED_R  = 2.5;
LED_ZC = WB + 22.0;  // centre Z  (= 25.0 mm)
// Evenly spaced over button span, 6 holes
LED_STEP = (BTN_XC[3] - BTN_XC[0]) / 5;
LED_XC   = [for (i=[0:5]) BTN_XC[0] + i * LED_STEP];

// 2 mode buttons — 16 × 8 mm rounded rectangles
MODE_W  = 16.0;
MODE_H  = 8.0;
MODE_ZC = WB + 8.0;  // centre Z  (= 11.0 mm)
MODE_XC = [BTN_XC[0] - 2, BTN_XC[2] - 2];

/* ── BACK PANEL ────────────────────────────────────────────────────── */
// All ports centred at H/2 = 16 mm (within BOT_H = 29.5 mm)
USBA_PORT_ZC = H / 2;  // = 16.0 mm
USBA_W       = 12.5;
USBA_H       = 4.5;
USBA_PITCH   = 18.0;
// C1–C4 output port centres
USBA_XC = [for (i=[0:3]) WS + 12.0 + i * USBA_PITCH];  // [14.5, 32.5, 50.5, 68.5]
KBD_XC  = USBA_XC[3] + USBA_PITCH + 3.0;  // keyboard input  (= 89.5 mm)
USBC_XC = KBD_XC + USBA_PITCH;            // USB-C power     (= 107.5 mm)
USBC_W  = 9.0;
USBC_H  = 3.5;

/* ── VENTILATION (right side) ──────────────────────────────────────── */
VENT_W       = 1.5;
VENT_L       = 28.0;
VENT_N       = 5;
VENT_ZC0     = WB + 12.0;  // first slot centre Z  (= 15.0 mm)
VENT_PITCH   = 5.0;

$fn = 64;

/* ══════════════════════════════════════════════════════════════════════
   HELPER MODULES
   ══════════════════════════════════════════════════════════════════════ */

// M3 boss with heat-set insert pocket (insert from top)
module m3_boss(h) {
    difference() {
        cylinder(r=BOSS_R, h=h);
        translate([0, 0, h - INSERT_DEPTH])
            cylinder(r=INSERT_R, h=INSERT_DEPTH + 0.1);
    }
}

// M3 screw through-hole
module m3_hole(h) {
    cylinder(r=SCREW_R, h=h + 0.2);
}

// Boss corner positions [x, y]
boss_corners = [
    [BOSS_INSET,     BOSS_INSET    ],
    [W-BOSS_INSET,   BOSS_INSET    ],
    [BOSS_INSET,     D-BOSS_INSET  ],
    [W-BOSS_INSET,   D-BOSS_INSET  ]
];

// Iterate corners
module at_corners() {
    for (c = boss_corners)
        translate([c[0], c[1], 0])
            children();
}

// Y-direction cylinder cutter (penetrates front or back wall)
// y_start: start Y of cut, len: length through wall (WS+2 for clean cuts)
// xc, zc: centre of hole
module y_cyl_cutter(r, xc, zc, y_start, len) {
    translate([xc, y_start, zc])
        rotate([90, 0, 0])
            cylinder(r=r, h=len);
}

// Rectangular wall cutter (front/back face, Y direction)
module y_rect_cutter(w, h, xc, zc, y_start, len) {
    translate([xc - w/2, y_start, zc - h/2])
        cube([w, len, h]);
}

/* ── Front panel cutouts ────────────────────────────────────────────── */
module front_cutouts() {
    y0 = -1;
    len = WS + 2;

    // Display opening
    translate([DISP_X, y0, DISP_Z])
        cube([DISP_W, len, DISP_H]);

    // 45° chamfer on top interior edge of display opening (bridge aid)
    translate([DISP_X, WS - DISP_CHAMFER, DISP_Z + DISP_H - DISP_CHAMFER])
        rotate([-45, 0, 0])
            cube([DISP_W, DISP_CHAMFER * 1.42, DISP_CHAMFER * 1.42]);

    // 4 select button holes
    for (bx = BTN_XC)
        y_cyl_cutter(BTN_R, bx, BTN_ZC, y0, len);

    // 6 status LED holes
    for (lx = LED_XC)
        y_cyl_cutter(LED_R, lx, LED_ZC, y0, len);

    // 2 mode buttons (rounded rect via hull)
    for (mx = MODE_XC)
        translate([mx - MODE_W/2 + MODE_H/2, y0, MODE_ZC - MODE_H/2])
            hull() {
                translate([0, 0, 0])
                    rotate([90, 0, 0]) cylinder(r=MODE_H/2, h=len);
                translate([MODE_W - MODE_H, 0, 0])
                    rotate([90, 0, 0]) cylinder(r=MODE_H/2, h=len);
            }
}

/* ── Back panel cutouts ─────────────────────────────────────────────── */
module back_cutouts() {
    y0 = D - WS - 1;
    len = WS + 2;
    zc = USBA_PORT_ZC;

    // 4× USB-A output (C1–C4)
    for (bx = USBA_XC)
        y_rect_cutter(USBA_W, USBA_H, bx, zc, y0, len);

    // USB-A keyboard input
    y_rect_cutter(USBA_W, USBA_H, KBD_XC, zc, y0, len);

    // USB-C power (rounded rect)
    translate([USBC_XC - USBC_W/2 + USBC_H/2, y0, zc - USBC_H/2])
        hull() {
            rotate([90, 0, 0]) cylinder(r=USBC_H/2, h=len);
            translate([USBC_W - USBC_H, 0, 0])
                rotate([90, 0, 0]) cylinder(r=USBC_H/2, h=len);
        }
}

/* ── Right-side ventilation slots ───────────────────────────────────── */
module vent_slots() {
    for (i = [0 : VENT_N-1]) {
        zc = VENT_ZC0 + i * VENT_PITCH;
        translate([W - WS - 1, D/2 - VENT_L/2, zc - VENT_W/2])
            cube([WS + 2, VENT_L, VENT_W]);
    }
}

/* ══════════════════════════════════════════════════════════════════════
   BOTTOM SHELL (main tray)
   Print: floor face down (Z=0 on build plate), open top facing up.
   ══════════════════════════════════════════════════════════════════════ */
module bottom_shell() {
    difference() {
        // Outer body
        cube([W, D, BOT_H]);

        // Interior pocket — open at top
        translate([WS, WS, WB])
            cube([W - 2*WS, D - 2*WS, BOT_H - WB + 0.1]);

        // Panel cutouts
        front_cutouts();
        back_cutouts();
        vent_slots();
    }

    // Corner bosses (added, not subtracted)
    translate([0, 0, WB])
        at_corners()
            m3_boss(BOSS_H);

    // Alignment rib on top rim (mates with lid step groove)
    translate([WS, WS, BOT_H - RIB_H])
        difference() {
            cube([W - 2*WS, D - 2*WS, RIB_H]);
            translate([RIB_T, RIB_T, -0.1])
                cube([W - 2*WS - 2*RIB_T, D - 2*WS - 2*RIB_T, RIB_H + 0.2]);
        }
}

/* ══════════════════════════════════════════════════════════════════════
   TOP LID (flat cover)
   Print: outer face down (flip 180° in slicer — step faces up during print).
   ══════════════════════════════════════════════════════════════════════ */
module top_lid() {
    g = FIT_GAP;

    difference() {
        union() {
            // Flat top panel
            cube([W, D, WT]);
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

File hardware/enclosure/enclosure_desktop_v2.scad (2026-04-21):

/* ══════════════════════════════════════════════════════════════════════
   HIDProxBox Enclosure — Desktop v2 (Enhanced Slab)
   Parametric OpenSCAD model · DVI-38

   Builds on Option A (DVI-35 / enclosure.scad) with:
     • 3° ergonomic tilt — rear is 32 mm, front drops to ~24 mm
     • Rubber-foot boss pockets (×4) on underside
     • Dual-side chevron ventilation (left + right)
     • Port-label channels (0.4 mm deep grooves above port groups)
     • Recessed logo plate area on top lid
     • Wider interior cable-management clip boss near power

   Hardware compatibility is unchanged:
     — Same 175 × 90 mm footprint as v1
     — Same port centre-lines (back panel USB-A and USB-C positions)
     — Same front-panel display + button + LED layout
     — Same M3 × 4 mm heat-set inserts (×4), M3 × 10 mm lid screws

   Print orientation
     Bottom shell : floor face down, open top up (rear wall is tallest).
     Top lid      : outer face down, flip 180° in slicer.
   ══════════════════════════════════════════════════════════════════════ */

/* ── MAIN FOOTPRINT (mm) ────────────────────────────────────────────── */
W  = 175;    // exterior width (X)
D  = 90;     // exterior depth (Y)
H_REAR = 32; // exterior height at rear (tallest side)
H_FRONT = 24;// exterior height at front (tilt creates a wedge profile)
// The tilt is applied as a linear height gradient front→rear.
// TILT_SLOPE = (H_REAR - H_FRONT) / D
TILT_SLOPE = (H_REAR - H_FRONT) / D;

/* ── WALL THICKNESS ────────────────────────────────────────────────── */
WS = 2.5;   // side walls
WB = 3.0;   // base / floor
WT = 2.5;   // lid panel thickness

/* ── LID / SPLIT ───────────────────────────────────────────────────── */
LID_STEP_H  = 1.5;
LID_TOTAL_H = WT + LID_STEP_H;  // 4.0 mm
// The split-plane follows the tilt: at depth y the shell wall height is:
//   shell_h(y) = H_FRONT + TILT_SLOPE * y - WT
// We keep the lid flat on the outside and tapered on the bottom edge.
BOT_H_FRONT = H_FRONT - WT;   // shell height at front = 21.5 mm
BOT_H_REAR  = H_REAR  - WT;   // shell height at rear  = 29.5 mm

/* ── ALIGNMENT RIB ─────────────────────────────────────────────────── */
RIB_T   = 1.0;
RIB_H   = 0.8;
FIT_GAP = 0.15;

/* ── M3 FASTENERS ──────────────────────────────────────────────────── */
SCREW_R      = 1.65;
INSERT_R     = 2.0;
INSERT_DEPTH = 6.0;
BOSS_R       = 5.0;
BOSS_H_MIN   = 14.0;   // boss height at front corners (shorter due to tilt)
BOSS_H_MAX   = 22.0;   // boss height at rear corners
BOSS_INSET   = WS + BOSS_R + 1.5;   // = 9.0 mm from outer edge

/* ── RUBBER FOOT POCKETS (underside) ───────────────────────────────── */
FOOT_R     = 6.5;    // pocket radius (fits Ø12 mm rubber foot)
FOOT_DEPTH = 1.5;    // recess depth
FOOT_INSET = 10.0;   // from outer edge to pocket centre

/* ── FRONT PANEL ───────────────────────────────────────────────────── */
// Heights below are measured from the FRONT floor (Z=0).
DISP_X       = WS + 8.0;  // 10.5 mm from left outer edge
DISP_Z       = WB + 4.0;  // 7.0 mm from floor
DISP_W       = 73.0;
DISP_H       = 22.0;
DISP_CHAMFER = 1.5;

SEP_X = DISP_X + DISP_W + 4.0;   // = 87.5 mm

BTN_R  = 8.0;
BTN_ZC = WB + 13.0;   // 16.0 mm from floor (lowered 2 mm vs v1 for tilt)
BTN_XC = [SEP_X+14, SEP_X+30, SEP_X+46, SEP_X+62];

LED_R    = 2.5;
LED_ZC   = WB + 19.5;  // 22.5 mm from floor
LED_STEP = (BTN_XC[3] - BTN_XC[0]) / 5;
LED_XC   = [for (i=[0:5]) BTN_XC[0] + i * LED_STEP];

MODE_W  = 16.0;
MODE_H  = 8.0;
MODE_ZC = WB + 7.0;   // 10.0 mm
MODE_XC = [BTN_XC[0] - 2, BTN_XC[2] - 2];

// Port-label groove above button zone (shallow channel, cosmetic)
LABEL_GROOVE_H  = 0.4;   // depth
LABEL_GROOVE_W  = 1.2;   // width
LABEL_GROOVE_ZC = WB + 2.0;  // just above the mode buttons

/* ── BACK PANEL ────────────────────────────────────────────────────── */
// Vertical centre measured from REAR floor (rear is tallest).
USBA_PORT_ZC = H_REAR / 2;  // = 16.0 mm — same as v1
USBA_W       = 12.5;
USBA_H       = 4.5;
USBA_PITCH   = 18.0;
USBA_XC = [for (i=[0:3]) WS + 12.0 + i * USBA_PITCH];
KBD_XC  = USBA_XC[3] + USBA_PITCH + 3.0;
USBC_XC = KBD_XC + USBA_PITCH;
USBC_W  = 9.0;
USBC_H  = 3.5;

/* ── LOGO PLATE RECESS (top lid) ───────────────────────────────────── */
LOGO_W     = 45.0;    // width of recess
LOGO_D     = 14.0;    // depth (Y) of recess
LOGO_DEPTH = 0.8;     // how far it sinks into the lid
LOGO_XC    = W / 2;   // centred on lid
LOGO_YC    = D * 0.30; // 30 % from front

/* ── VENTILATION — BOTH SIDES (chevron slots) ──────────────────────── */
// Left side (X=0 wall) and right side (X=W wall)
// Chevron = two angled rectangles forming a V shape per unit
VENT_W        = 1.5;    // slot width
VENT_L        = 24.0;   // half-leg length of chevron
VENT_ANGLE    = 30;     // degrees from vertical
VENT_N        = 5;      // number of chevron units per side
VENT_ZC0      = WB + 10.0;
VENT_PITCH    = 5.0;
VENT_Y_CENTER = D / 2;  // centred front-to-back

/* ── CABLE CLIP BOSS (interior, near USB-C power) ──────────────────── */
// Small upright tower with a notch to clip a USB-C cable tidy
CLIP_X = USBC_XC - 10.0;  // interior X near power port
CLIP_R = 2.5;
CLIP_H = 8.0;
CLIP_SLOT_W = 4.0;    // slot width (cable pass-through)
CLIP_SLOT_H = 3.0;

$fn = 64;

/* ══════════════════════════════════════════════════════════════════════
   HELPER MODULES
   ══════════════════════════════════════════════════════════════════════ */

// Height of shell wall at a given Y depth (tilt)
function shell_h(y) = H_FRONT + TILT_SLOPE * y;

// Boss height from floor at given Y (so top of boss reaches lid split plane)
function boss_h(y) = shell_h(y) - WT - WB;

module m3_boss(h) {
    difference() {
        cylinder(r=BOSS_R, h=h);
        translate([0, 0, h - INSERT_DEPTH])
            cylinder(r=INSERT_R, h=INSERT_DEPTH + 0.1);
    }
}

module m3_hole(h) {
    cylinder(r=SCREW_R, h=h + 0.2);
}

// Rubber foot pocket (recess into floor bottom face)
module foot_pocket() {
    translate([0, 0, -0.1])
        cylinder(r=FOOT_R, h=FOOT_DEPTH + 0.1);
}

boss_corners = [
    [BOSS_INSET,   BOSS_INSET  ],
    [W-BOSS_INSET, BOSS_INSET  ],
    [BOSS_INSET,   D-BOSS_INSET],
    [W-BOSS_INSET, D-BOSS_INSET]
];

module y_cyl_cutter(r, xc, zc, y_start, len) {
    translate([xc, y_start, zc])
        rotate([90, 0, 0])
            cylinder(r=r, h=len);
}

module y_rect_cutter(w, h, xc, zc, y_start, len) {
    translate([xc - w/2, y_start, zc - h/2])
        cube([w, len, h]);
}

/* ── Front panel cutouts ────────────────────────────────────────────── */
module front_cutouts() {
    y0  = -1;
    len = WS + 2;

    // Display opening
    translate([DISP_X, y0, DISP_Z])
        cube([DISP_W, len, DISP_H]);
    // Bridge chamfer
    translate([DISP_X, WS - DISP_CHAMFER, DISP_Z + DISP_H - DISP_CHAMFER])
        rotate([-45, 0, 0])
            cube([DISP_W, DISP_CHAMFER * 1.42, DISP_CHAMFER * 1.42]);

    // 4 select buttons
    for (bx = BTN_XC)
        y_cyl_cutter(BTN_R, bx, BTN_ZC, y0, len);

    // 6 status LEDs
    for (lx = LED_XC)
        y_cyl_cutter(LED_R, lx, LED_ZC, y0, len);

    // 2 mode buttons (rounded rect)
    for (mx = MODE_XC)
        translate([mx - MODE_W/2 + MODE_H/2, y0, MODE_ZC - MODE_H/2])
            hull() {
                rotate([90, 0, 0]) cylinder(r=MODE_H/2, h=len);
                translate([MODE_W - MODE_H, 0, 0])
                    rotate([90, 0, 0]) cylinder(r=MODE_H/2, h=len);
            }

    // Label groove above mode/button zone (cosmetic separator line)
    translate([SEP_X, y0, LABEL_GROOVE_ZC - LABEL_GROOVE_W/2])
        cube([W - SEP_X - WS - 2, len, LABEL_GROOVE_W]);
}

/* ── Back panel cutouts ─────────────────────────────────────────────── */
module back_cutouts() {
    y0  = D - WS - 1;
    len = WS + 2;
    zc  = USBA_PORT_ZC;

    for (bx = USBA_XC)
        y_rect_cutter(USBA_W, USBA_H, bx, zc, y0, len);

    y_rect_cutter(USBA_W, USBA_H, KBD_XC, zc, y0, len);

    translate([USBC_XC - USBC_W/2 + USBC_H/2, y0, zc - USBC_H/2])
        hull() {
            rotate([90, 0, 0]) cylinder(r=USBC_H/2, h=len);
            translate([USBC_W - USBC_H, 0, 0])
                rotate([90, 0, 0]) cylinder(r=USBC_H/2, h=len);
        }
}

/* ── Chevron vent slot (single leg) ────────────────────────────────── */
// Generates one angled rectangle; call twice mirrored for a full chevron.
module chevron_leg(xface, flip) {
    sign = flip ? -1 : 1;
    rotate([0, 0, sign * VENT_ANGLE])
        translate([-VENT_W/2, 0, 0])
            cube([VENT_W, VENT_L, 100]);  // Z clipped by difference
}
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

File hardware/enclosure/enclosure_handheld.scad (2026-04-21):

/* ══════════════════════════════════════════════════════════════════════
   HIDProxBox Enclosure — Handheld / Portable  (rev 2)
   Parametric OpenSCAD model · DVI-38 · constrained by DVI-39

   Redesigned to meet DVI-39 hardware constraint spec:
     • Footprint  : 90 × 50 mm  (≤ 90 × 50 mm target)
     • SBC        : Raspberry Pi Zero 2 W (65 × 30 mm)
     • MCUs       : 4× CH552T on 10 mm standoffs stacked above Pi
     • Buttons    : 4× computer select (12 mm caps) + 2× mode
     • LEDs       : 4× status (3 mm dia), one per select button
     • Ports      : 4× USB-A output + 1× USB-A keyboard input (back panel)
                    1× USB-C charging / power (right side)
     • Battery    : placeholder void for slim LiPo TBD
                    (chemistry / capacity unresolved — see DVI-39 §11)
     • Display    : omitted (optional per spec; footprint precludes it)

   OVERALL DIMENSIONS: 90 × 50 × 30 mm

   TWO-PIECE FDM DESIGN
     Bottom shell : floor face down, open top up (no supports needed)
     Top cap      : outer face down, flip 180° in slicer

   FASTENERS: 4× M2.5 heat-set inserts + 4× M2.5 × 8 mm pan-head screws

   Grip ridges run along the left and right long sides (3 per side).
   ══════════════════════════════════════════════════════════════════════ */

/* ── OUTER SHELL ────────────────────────────────────────────────────── */
W  = 90;    // exterior width   (X) — landscape
D  = 50;    // exterior depth   (Y)
H  = 30;    // exterior height  (Z)
CR = 4.0;   // XY corner radius

/* ── WALL THICKNESS ────────────────────────────────────────────────── */
WS = 2.0;
WB = 2.5;
WT = 2.0;

/* ── LID / SPLIT ───────────────────────────────────────────────────── */
LID_STEP_H  = 1.2;
LID_TOTAL_H = WT + LID_STEP_H;   // 3.2 mm
BOT_H       = H - WT;            // 28.0 mm

/* ── ALIGNMENT RIB ─────────────────────────────────────────────────── */
RIB_T   = 0.8;
RIB_H   = 0.7;
FIT_GAP = 0.15;

/* ── M2.5 FASTENERS ────────────────────────────────────────────────── */
SCREW_R      = 1.4;    // M2.5 clearance
INSERT_R     = 1.75;   // M2.5 heat-set insert pocket
INSERT_DEPTH = 4.5;
BOSS_R       = 3.8;
BOSS_H       = 20.0;   // from floor to top of boss (clamped well below lid)
BOSS_INSET   = WS + BOSS_R + 1.0;   // = 6.8 mm from outer edge

/* ── FRONT FACE (Y=0)
   Layout (X from left, Z from floor):

   Z=24 ○    ○    ○    ○       ← 4× status LEDs (3 mm dia), one per computer
   Z=16 ●    ●         ●    ●  ← 4× select buttons (12 mm), pairs C1+C2 / C3+C4
   Z= 8           ▬ ▬          ← 2× mode buttons, centred in inter-group gap

   Groups are separated by a 22 mm gap (X = 34 … 56 mm) to give a visual
   cue distinguishing the two pairs.  Mode buttons sit in that gap at Z = 8.
   ──────────────────────────────────────────────────────────────────── */
// 12 mm diameter select buttons (smaller than desktop 16 mm — handheld ergonomics)
BTN_R   = 6.0;
BTN_ZC  = WB + 13.5;   // = 16.0 mm from floor
BTN_XC  = [12.0, 28.0, 62.0, 78.0];
// Group 1 right edge: 28+6=34; Group 2 left edge: 62-6=56 → 22 mm gap

// 3 mm status LEDs (one per button, tangent above — "space allows" threshold per DVI-39)
LED_R   = 1.5;
LED_ZC  = WB + 21.5;   // = 24.0 mm from floor (tangent: 24-1.5=22.5 > BTN top 22)
LED_XC  = BTN_XC;      // directly above respective select button

// 2× mode buttons — centred in the 22 mm inter-group gap
MODE_W  = 9.0;    // slightly narrower than desktop to fit gap
MODE_H  = 4.0;
MODE_ZC = WB + 5.5;    // = 8.0 mm from floor (tangent below select buttons)
MODE_XC = [40.0, 50.0];
// Mode btn1 X-span: [35.5, 44.5], mode btn2: [45.5, 54.5]
// Clearance from select groups: 34→35.5 (1.5 mm) and 54.5→56 (1.5 mm) ✓

/* ── BACK PANEL — 4× USB-A output + 1× USB-A keyboard input ─────────── */
// All ports centred at H/2 = 15 mm (mid-height of 30 mm shell)
USBA_PORT_ZC = H / 2;   // = 15.0 mm
USBA_W       = 12.5;
USBA_H       = 4.5;
USBA_PITCH   = 15.0;    // 15 mm pitch (vs. 18 mm desktop — 90 mm back panel)
// C1–C4 output port centres
USBA_XC = [for (i=[0:3]) WS + 8.0 + i * USBA_PITCH];
         // = [10.0, 25.0, 40.0, 55.0]
KBD_XC  = USBA_XC[3] + USBA_PITCH;   // keyboard input  (= 70.0 mm)
// Keyboard right edge: 70+6.25=76.25 < 88 mm (interior right) ✓

/* ── RIGHT SIDE — USB-C charging / power ────────────────────────────── */
USBC_W  = 9.0;
USBC_H  = 3.5;
USBC_ZC = H / 2;   // = 15.0 mm
USBC_YC = D / 2;   // = 25.0 mm front-to-back

/* ── BATTERY PLACEHOLDER ────────────────────────────────────────────── */
// Chemistry and capacity TBD (DVI-39 §11 §8).  Uncomment when spec is confirmed.
// A representative slim LiPo (e.g. 401660 ~150 mAh, or 503450 ~800 mAh)
// can fit in the interior beside the Pi Zero 2W footprint (65 × 30 mm)
// or in a second layer above the CH552T stack.  Set to true to preview the void.
SHOW_BATTERY_VOID  = false;
BAT_W  = 18.0;   // placeholder width  (X)
BAT_D  = 38.0;   // placeholder depth  (Y)
BAT_H  =  7.0;   // placeholder height (Z) — sits on floor
BAT_X  = W - WS - BAT_W - 1.0;   // right side of interior
BAT_Y  = WS + 4.0;

/* ── GRIP RIDGES (left + right long sides) ───────────────────────────── */
GRIP_W  = 1.5;   // ridge base width (Y)
GRIP_H  = 0.8;   // ridge protrusion (X outward)
GRIP_N  = 3;
GRIP_Y0    = D * 0.25;
GRIP_PITCH = D * 0.22;

/* ── VENTILATION (left side wall) ────────────────────────────────────── */
VENT_W  = 1.2;
VENT_L  = 20.0;
VENT_N  = 4;
VENT_ZC0    = WB + 8.0;   // = 10.5 mm from floor
VENT_PITCH  = 4.0;
VENT_YC     = D / 2;

$fn = 48;

/* ══════════════════════════════════════════════════════════════════════
   HELPERS
   ══════════════════════════════════════════════════════════════════════ */

module rounded_rect(w, d, h, r) {
    hull() {
        for (x = [r, w-r]) for (y = [r, d-r])
            translate([x, y, 0]) cylinder(r=r, h=h);
    }
}

module m25_boss(h) {
    difference() {
        cylinder(r=BOSS_R, h=h);
        translate([0, 0, h - INSERT_DEPTH])
            cylinder(r=INSERT_R, h=INSERT_DEPTH + 0.1);
    }
}

module m25_hole(h) {
    cylinder(r=SCREW_R, h=h + 0.2);
}

boss_corners = [
    [BOSS_INSET,   BOSS_INSET  ],
    [W-BOSS_INSET, BOSS_INSET  ],
    [BOSS_INSET,   D-BOSS_INSET],
    [W-BOSS_INSET, D-BOSS_INSET]
];

// Y-direction cylinder cutter (front / back wall)
module y_cyl_cutter(r, xc, zc, y_start, len) {
    translate([xc, y_start, zc])
        rotate([90, 0, 0])
            cylinder(r=r, h=len);
}
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

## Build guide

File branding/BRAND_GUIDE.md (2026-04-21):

# HIDProxBox Brand Style Guide

> Version 1.0 · April 2026

---

## Brand Essence

**HIDProxBox** is a hardware-first open-source project. The visual identity reflects its core values: precision, transparency, and technical craftsmanship. The aesthetic draws from embedded-systems culture — circuit boards, terminal interfaces, and clean engineering — without veering into clichéd "hacker" imagery.

**Tagline:** *One keyboard. Four computers. Zero software on the targets.*

---

## Logo

### Files

| File | Use case |
|---|---|
| `branding/icon.svg` | Favicon, app icon, avatar (64×64 base, scalable) |
| `branding/logo-dark.svg` | Dark backgrounds, GitHub README header, dark mode UI |
| `branding/logo-light.svg` | Light backgrounds, print, light mode UI |
| `branding/social-preview.svg` | GitHub repository social preview (1280×640) |
| `branding/readme-banner.svg` | README header banner (1280×200) |

### Icon mark

The icon depicts the HIDProxBox proxy concept directly:
- **Cyan dot + line (left):** A single keyboard/mouse input source
- **Dark rounded box (center):** The HIDProxBox hardware, styled as an IC package with corner pads
- **Blue dot (center inside):** The routing/switching node
- **Blue lines + dots (right):** Four target computers

The IC-package corner pads and internal bus give the icon a deliberate circuit-board character at any scale.

### Wordmark

The wordmark uses three typographic segments in three brand colors:

```
HID     Prox    Box
cyan    white   blue
```

- **HID** — `#22D3EE` (Cyan 400) — identifies the Human Interface Device protocol
- **Prox** — `#F1F5F9` (Slate 50) — the proxy/switching core
- **Box** — `#3B82F6` (Blue 500) — the hardware box

On light backgrounds, use the light-variant colors: `#0891B2` / `#0F172A` / `#2563EB`.

### Clear space

Maintain a minimum clear space of **0.5× the icon height** on all sides. Never crowd the logo against other elements.

### Don't

- Don't recolor individual wordmark segments arbitrarily
- Don't stretch or distort the icon
- Don't place the dark logo on a dark background (use the light variant instead)
- Don't apply drop shadows or glows to the logo
- Don't use the wordmark alone without the icon in primary applications

---

## Color Palette

### Primary colors

| Name | Hex | RGB | Use |
|---|---|---|---|
| **Midnight** | `#090D1A` | 9, 13, 26 | Page/card background (dark) |
| **Navy** | `#0F172A` | 15, 23, 42 | Surface background (dark) |
| **Slate** | `#1E293B` | 30, 41, 59 | Card/box fill, icon body |

### Accent colors

| Name | Hex | RGB | Use |
|---|---|---|---|
| **Cyan** | `#22D3EE` | 34, 211, 238 | Input indicator, "HID" wordmark, active state |
| **Electric Blue** | `#3B82F6` | 59, 130, 246 | Output/computer connections, "Box" wordmark, primary CTA |

### Text colors

| Name | Hex | RGB | Use |
|---|---|---|---|
| **White** | `#F1F5F9` | 241, 245, 249 | Primary text on dark |
| **Muted** | `#94A3B8` | 148, 163, 184 | Secondary/body text on dark |
| **Dim** | `#475569` | 71, 85, 105 | Tertiary/caption text on dark |
| **Border** | `#334155` | 51, 65, 85 | Dividers, card borders |

### Light-mode accent colors

When rendering on white or light-grey backgrounds, use these slightly darker variants to preserve contrast:

| Dark variant | Light variant |
|---|---|
| `#22D3EE` Cyan | `#0891B2` Cyan 600 |
| `#3B82F6` Blue | `#2563EB` Blue 600 |

### Color roles summary

- **Cyan** = input / source / active selection
- **Blue** = output / destination / interactive
- **White** = content / data
- **Dark navy/slate** = structure / background / hardware

---

## Typography

### Wordmark / Code / Data

```
Font:   JetBrains Mono, Fira Code, Courier New, monospace
Weight: 700 (Bold)
Usage:  Logo wordmark, code samples, hex values, terminal output
```

### UI / Body / Marketing

```
Font:   Inter, system-ui, -apple-system, sans-serif
Weight: 400 (Regular) / 600 (Semi-bold) / 700 (Bold)
Usage:  Taglines, feature descriptions, badge labels, README prose
```

### Type scale

| Role | Size | Weight | Color |
|---|---|---|---|
| Hero title | 80–90px | 700 | white (three-color split) |
| Section heading | 48–56px | 700 | white |
| Subheading | 28–32px | 600 | Muted |
| Body | 16–18px | 400 | Muted |
| Caption / badge | 12–14px | 600 | Dim |
| Code | 14–16px | 400–700 | Cyan or white |

---

## Iconography & Visual Language

- Use **monoline** icon style (1.5–2px strokes) to match the logo's circuit-trace aesthetic
- Prefer **rounded linecaps** and **rounded joins**
- Use **dots at endpoints** to signify connections (circuit-pad visual language)
- Use **dashed lines** sparingly to indicate non-active or potential connections
- Avoid filled blob icons; prefer outline-on-dark

---

## Background Patterns

The brand uses a **dot-grid background pattern** for large surfaces (social cards, banners):

```
Pattern:  40×40px repeating tile
Element:  1px circle at center
Color:    #1E2D45 (slightly lighter than Midnight)
Opacity:  70–90%
```

Circuit trace accents (thin lines that make 90° turns with junction dots) may be added to backgrounds for texture, using the same `#1E2D45` color at low opacity. Keep them subtle — they should read as texture, not content.

---

## Badge / Pill Style

Feature badges use this treatment:

```
Background:  #1E293B
Border:      1px solid — Cyan or Blue, depending on category
Border-radius: 5–6px
Padding:     8px 12px
Font:        Inter, 13px, 600
Text color:  accent or Muted (94A3B8)
Leading dot: 5px filled circle in accent color
```

Use **Cyan** borders for input-related features (keyboard, source, wired).  
Use **Blue** borders for output-related features (computers, Bluetooth, USB).

---

## GitHub-Specific Usage

| Location | Asset | Notes |
|---|---|---|
| Repository social preview | `social-preview.svg` → export to PNG | GitHub requires a PNG; export at 1280×640 |
| README header | `readme-banner.svg` | Reference as `./branding/readme-banner.svg` in README |
| README inline logo | `logo-dark.svg` | Use with `align="left"` for floating header |
| Issues / Discussions avatar | `icon.svg` | 64px base, GitHub will resize |

### Exporting SVG → PNG

GitHub's social preview field requires a PNG. Export `social-preview.svg` at its native 1280×640 resolution:

```bash
# Using Inkscape (headless)
inkscape branding/social-preview.svg \
  --export-type=png \
  --export-filename=branding/social-preview.png \
  --export-width=1280

# Using rsvg-convert
rsvg-convert -w 1280 -h 640 branding/social-preview.svg -o branding/social-preview.png

# Using Chrome headless
chrome --headless --screenshot=branding/social-preview.png \
  --window-size=1280,640 branding/social-preview.svg
```

---

## Voice & Tone (Brand Alignment)

Although primarily a visual guide, keep these tone principles in mind for copy that appears alongside brand assets:

- **Direct** — state what it does, not what it "empowers" you to do
- **Technical but not jargon-heavy** — assume a capable audience; don't over-explain standard concepts
- **Hardware-grounded** — lead with the physical reality (chips, wires, buttons) before abstractions
- **Open-source honest** — acknowledge trade-offs, show real commands, credit the stack

---

*This guide covers v1.0 of the HIDProxBox brand identity. Update this document when any asset is revised.*

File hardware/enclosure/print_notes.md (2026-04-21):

# HIDProxBox Enclosure — Print Notes

Three variants across two tickets (DVI-35 original · DVI-38 enhanced):

| Variant | File | Footprint | Ticket |
|---|---|---|---|
| Desktop original | `enclosure.scad` | 175 × 90 × 32 mm | DVI-35 |
| Desktop v2 (enhanced) | `enclosure_desktop_v2.scad` | 175 × 90 × 22–32 mm (tilt) | DVI-38 |
| Handheld | `enclosure_handheld.scad` | 90 × 50 × 30 mm | DVI-38 |

See `design-rationale.md` for the motivation behind v2 changes and handheld design decisions.

---

## Desktop v2 (`enclosure_desktop_v2.scad`)

### Parts

| File | Description | Print orientation |
|---|---|---|
| `stl/desktop_v2_bottom.stl` | Shell with tilted walls, vent slots both sides | Floor face down, open top up |
| `stl/desktop_v2_lid.stl` | Wedge-profile flat lid with logo recess | **Flip 180°** — outer face down, step faces up |

### Print settings

| Setting | Value |
|---|---|
| Material | PLA or PETG |
| Layer height | 0.20 mm |
| Perimeters / walls | 3 |
| Infill | 20 % grid |
| Supports | **None required** |
| Print speed | 40–60 mm/s |
| Estimated time | 5–7 hr total |

### Notes

- Front-face display opening (73 mm) requires slicer bridging detection or a 45° chamfer bridge (already included). No manual supports needed.
- The tilted shell has a 24 mm front / 32 mm rear height. Orient the rear face toward the back of the build plate so the rear wall is tallest.
- Stick Ø12 mm rubber feet into the four floor recesses (1.5 mm deep) before assembling.
- Logo badge: the 45 × 14 mm recess on the lid accepts a laser-cut or printed acrylic badge; secure with thin double-sided tape.

### Assembly

1. Heat-set 4× M3 inserts into corner bosses (6 mm deep pockets, 18 mm boss at rear, ~14 mm at front).
2. Install Raspberry Pi on standoffs on the 3 mm floor; route cables to front (display, buttons, LEDs) and back (USB ports).
3. Seat lid — step rebate registers on alignment rib.
4. Fasten with 4× M3 × 10 mm pan-head screws (lid step adds ~1.5 mm; M3 × 8 mm from v1 may be too short).

### Hardware BOM (desktop v2)

| Qty | Part |
|---|---|
| 4 | M3 × 4 mm OD5 heat-set inserts |
| 4 | M3 × 10 mm pan-head machine screws |
| 4 | Ø12 mm self-adhesive rubber feet |
| 1 | Logo badge, 45 × 14 mm (optional) |

---

## Handheld (`enclosure_handheld.scad`) — rev 2

Redesigned per DVI-39 hardware constraint spec.  See `design-rationale.md` for full change log.

### Parts

| File | Description | Print orientation |
|---|---|---|
| `stl/handheld_bottom.stl` | Shell with grip ridges, back-panel ports, left-side vents | Floor face down |
| `stl/handheld_top.stl` | Flat cap | **Flip 180°** — outer face down |

### Print settings

| Setting | Value |
|---|---|
| Material | PETG preferred (more flexible, less brittle for handheld) |
| Layer height | 0.15 mm (finer detail for grip ridges) |
| Perimeters / walls | 4 (handheld sees more flexing) |
| Infill | 25 % gyroid |
| Supports | **None required** |
| Print speed | 35–45 mm/s |
| Estimated time | 3–4 hr total |

### Notes

- Port placement: 4× USB-A output + 1× USB-A input exit the back panel; USB-C power/charge enters the right side.
- Grip ridges: three triangular ridges per long side — do not fill or remove them.
- No display opening (display omitted at this form factor — see DVI-39 §11).
- Battery void: enable `SHOW_BATTERY_VOID = true` in the SCAD before printing to verify battery fit. Actual battery cutout TBD once DVI-39 battery spec is confirmed.

### Assembly

1. Heat-set 4× M2.5 inserts into corner bosses (4.5 mm deep pockets, boss height 20 mm).
2. Install Pi Zero 2W on 3 mm standoffs above the 2.5 mm floor.
3. Install 4× CH552T boards on 10 mm standoffs above the Pi.
4. Route USB cables to back panel before seating top cap.
5. Install battery once spec confirmed (void located beside Pi Zero 2W footprint).
6. Seat top cap; fasten with 4× M2.5 × 8 mm pan-head screws.

### Hardware BOM (handheld)

| Qty | Part |
|---|---|
| 4 | M2.5 × OD4 × 3 mm heat-set inserts |
| 4 | M2.5 × 8 mm pan-head machine screws |
| 4 | 12 mm momentary push-button caps (select, one per computer) |
| 2 | 9 × 4 mm momentary push-button (mode) |
| 4 | 3 mm LED (status, one per computer) |
| 1 | LiPo battery — chemistry/capacity TBD (DVI-39 §8) |

---

## Generating STLs

### Desktop original (Python/manifold3d)

```bash
cd hardware/enclosure
python3 generate_stl.py
# Outputs: stl/enclosure_bottom.stl, stl/enclosure_top_lid.stl
```

Requires: `pip3 install manifold3d numpy-stl`

### Desktop v2 and Handheld (OpenSCAD CLI)

```bash
cd hardware/enclosure

# Desktop v2 bottom
openscad -D 'PART="bottom"' -o stl/desktop_v2_bottom.stl enclosure_desktop_v2.scad

# Desktop v2 lid
openscad -D 'PART="top"' -o stl/desktop_v2_lid.stl enclosure_desktop_v2.scad

# Handheld bottom
openscad -D 'PART="bottom"' -o stl/handheld_bottom.stl enclosure_handheld.scad

# Handheld top
openscad -D 'PART="top"' -o stl/handheld_top.stl enclosure_handheld.scad
```

Requires: OpenSCAD 2021.01 or later (`brew install openscad` on macOS).

### Interactive preview

Open any `.scad` file in OpenSCAD and set `PART = "both"` to see the assembled view.
Use `PART = "bottom"` or `PART = "top"` before exporting STLs.

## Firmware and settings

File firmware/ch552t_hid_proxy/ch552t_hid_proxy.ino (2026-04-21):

/**
 * ch552t_hid_proxy.ino
 * HIDProxBox — CH552T secondary USB HID output  (one unit per computer)
 *
 * Each CH552T is permanently plugged into one computer's USB port.
 * The Raspberry Pi sends framed command packets over UART1 and the
 * CH552T translates them into USB HID reports on the host side.
 *
 * Additionally, the Pi can command the CH552T to show whether its
 * computer is currently the "active" (selected) one via an LED.
 *
 * ── Frame Format (Pi → CH552T via UART1) ─────────────────────────────────
 *
 *   [0xAA] [TYPE] [LEN] [DATA ...LEN bytes...] [CHECKSUM]
 *
 *   TYPE   LEN   Description
 *   ────   ───   ──────────────────────────────────────────────────────────
 *   0x01    8    Keyboard report: [modifier, 0, key1..key6]
 *   0x02    4    Mouse report:    [buttons, X (int8), Y (int8), W (int8)]
 *   0x03    2    Consumer report: [usage_lo, usage_hi]
 *   0x10    1    Set-active LED:  0x01=active (LED on), 0x00=inactive (off)
 *   0xFE    0    Ping (no-op — wakes UART)
 *   0xFF    0    Reset: release all keys, clear mouse buttons
 *
 *   CHECKSUM = XOR of TYPE ^ LEN ^ DATA[0] ^ ... ^ DATA[N-1]
 *
 * ── LED Behaviour ─────────────────────────────────────────────────────────
 *
 *   ACTIVE_LED  (P3.4, active-low):
 *     • Solid ON  — this computer is the currently selected KVM target.
 *     • Solid OFF — standby (another computer is selected).
 *     • Fast blink (during RX) — data is being forwarded to this computer.
 *
 *   STATUS_LED  (P1.4, active-low, optional):
 *     • Short blink on every valid received frame.
 *     • Rapid blink on checksum error (bad frame).
 *
 * ── Board Setup in Arduino IDE ────────────────────────────────────────────
 *
 *   Board manager URL:
 *     https://raw.githubusercontent.com/DeqingSun/ch55xduino/master/
 *     package_ch55xduino_mcs51_index.json
 *
 *   Tools → Board          : CH55x boards → CH552
 *   Tools → Clock Source   : 16 MHz (internal)
 *   Tools → Upload Method  : USB (bootloader)
 *   Tools → USB Settings   : USER CODE w/ 148B USB ram
 *
 * ── Wiring (per CH552T unit) ──────────────────────────────────────────────
 *
 *   CH552T P3.0 (RXD1) ─── Pi /dev/ttyUSBx TX    (3.3 V — no level shift)
 *   CH552T P3.1 (TXD1) ─── Pi /dev/ttyUSBx RX
 *   CH552T GND         ─── Pi GND
 *   CH552T USB D+/D−   ─── Computer USB port  (22 Ω series resistors)
 *   CH552T VCC (3.3 V) ─── 3.3 V supply
 *   Active LED         ─── P3.4 → 220 Ω → LED → GND  (active-low)
 *   Status LED         ─── P1.4 → 220 Ω → LED → GND  (active-low, optional)
 */

#include <USBHIDKeyboard.h>
#include <USBHIDMouse.h>

// ── Pin definitions ──────────────────────────────────────────────────────────
#define ACTIVE_LED_PIN   34    // P3.4  active-low — "this computer is selected"
#define STATUS_LED_PIN   14    // P1.4  active-low — frame-received blink (optional)

// ── Protocol constants ───────────────────────────────────────────────────────
#define FRAME_SOF         0xAA
#define TYPE_KEYBOARD     0x01
#define TYPE_MOUSE        0x02
#define TYPE_CONSUMER     0x03
#define TYPE_SET_ACTIVE   0x10
#define TYPE_PING         0xFE
#define TYPE_RESET        0xFF

#define MAX_PAYLOAD       16
#define UART_BAUD         115200

// ── Frame parser state machine ───────────────────────────────────────────────
typedef enum {
    WAIT_SOF,
    WAIT_TYPE,
    WAIT_LEN,
    WAIT_DATA,
    WAIT_CHECKSUM
} ParserState;

static ParserState  s_state   = WAIT_SOF;
static uint8_t      s_type    = 0;
static uint8_t      s_len     = 0;
static uint8_t      s_buf[MAX_PAYLOAD];
static uint8_t      s_idx     = 0;
static uint8_t      s_chk_acc = 0;

// ── Runtime state ────────────────────────────────────────────────────────────
static bool         s_active  = false;   // is this the selected computer?

// ── USB HID objects ──────────────────────────────────────────────────────────
USBHIDKeyboard_ Keyboard;
USBHIDMouse_    Mouse;

// ─────────────────────────────────────────────────────────────────────────────
void setup() {
    pinMode(ACTIVE_LED_PIN, OUTPUT);
    digitalWrite(ACTIVE_LED_PIN, HIGH);   // off (active-low)

    pinMode(STATUS_LED_PIN, OUTPUT);
    digitalWrite(STATUS_LED_PIN, HIGH);

    Serial1.begin(UART_BAUD);
    delay(500);   // let host enumerate

    // Three quick blinks = ready
    for (int i = 0; i < 3; i++) {
        led_active(true);  delay(80);
        led_active(false); delay(80);
    }
}

// ─────────────────────────────────────────────────────────────────────────────
void loop() {
    while (Serial1.available() > 0) {
        process_byte((uint8_t)Serial1.read());
    }
    delay(1);
}

// ─────────────────────────────────────────────────────────────────────────────
// Frame parser
// ─────────────────────────────────────────────────────────────────────────────
static void process_byte(uint8_t b) {
    switch (s_state) {

        case WAIT_SOF:
            if (b == FRAME_SOF) s_state = WAIT_TYPE;
            break;

        case WAIT_TYPE:
            s_type    = b;
            s_chk_acc = b;
            s_state   = WAIT_LEN;
            break;

        case WAIT_LEN:
            s_len     = b;
            s_chk_acc ^= b;
            s_idx     = 0;
            if      (s_len == 0)           s_state = WAIT_CHECKSUM;
            else if (s_len > MAX_PAYLOAD)  s_state = WAIT_SOF;   // oversize — resync
            else                           s_state = WAIT_DATA;
            break;

        case WAIT_DATA:
            s_buf[s_idx++] = b;
            s_chk_acc ^= b;
            if (s_idx >= s_len) s_state = WAIT_CHECKSUM;
            break;

        case WAIT_CHECKSUM:
            if (b == s_chk_acc) {
                dispatch_frame();
                blink_status();          // brief blink on valid frame
            } else {
                blink_error();           // rapid blink on checksum failure
            }
            s_state = WAIT_SOF;
            break;
    }
}

// ─────────────────────────────────────────────────────────────────────────────
// Frame dispatcher
// ─────────────────────────────────────────────────────────────────────────────
static void dispatch_frame() {
    switch (s_type) {

        case TYPE_KEYBOARD:
            if (s_len == 8) send_keyboard_report(s_buf);
            break;

        case TYPE_MOUSE:
            if (s_len == 4) send_mouse_report(s_buf);
            break;

        case TYPE_CONSUMER:
            if (s_len == 2) send_consumer_report(s_buf);
            break;

        case TYPE_SET_ACTIVE:
            // s_buf[0]: 0x01 = this computer is now selected, 0x00 = deselected
            if (s_len == 1) {
                s_active = (s_buf[0] == 0x01);
                led_active(s_active);
            }
            break;

        case TYPE_RESET:
            Keyboard.releaseAll();
            Mouse.release(MOUSE_LEFT | MOUSE_RIGHT | MOUSE_MIDDLE);
            break;

        case TYPE_PING:
            // No-op
            break;
    }
}

// ─────────────────────────────────────────────────────────────────────────────
// HID report senders
// ─────────────────────────────────────────────────────────────────────────────

/**
 * Keyboard — 8-byte boot-compatible report
 *   buf[0] modifier  buf[1] reserved  buf[2..7] keycodes
 */
static void send_keyboard_report(const uint8_t *buf) {
    Keyboard.sendReport(buf[0], (uint8_t *)(buf + 2), 6);
}

/**
 * Mouse — 4-byte relative report
 *   buf[0] buttons  buf[1] X  buf[2] Y  buf[3] wheel  (all signed int8)
 */
static void send_mouse_report(const uint8_t *buf) {
    int8_t dx    = (int8_t)buf[1];
    int8_t dy    = (int8_t)buf[2];
    int8_t wheel = (int8_t)buf[3];
    uint8_t btns  = buf[0];

    if (btns & 0x01) Mouse.press(MOUSE_LEFT);   else Mouse.release(MOUSE_LEFT);
    if (btns & 0x02) Mouse.press(MOUSE_RIGHT);  else Mouse.release(MOUSE_RIGHT);
    if (btns & 0x04) Mouse.press(MOUSE_MIDDLE); else Mouse.release(MOUSE_MIDDLE);

    if (dx || dy || wheel) Mouse.move(dx, dy, wheel);
}

/**
 * Consumer (multimedia) — 2-byte usage ID, little-endian
 *   e.g. [0xE9, 0x00] = Volume Up
 */
static void send_consumer_report(const uint8_t *buf) {
    uint16_t usage = (uint16_t)buf[0] | ((uint16_t)buf[1] << 8);
#if defined(USBHID_CONSUMER_SUPPORTED)
    Keyboard.consumerPress(usage);
    delay(20);
    Keyboard.consumerRelease();
#else
    (void)usage;
#endif
}

// ─────────────────────────────────────────────────────────────────────────────
// LED helpers
// ─────────────────────────────────────────────────────────────────────────────

static void led_active(bool on) {
    // Active-low: LOW = LED on
    digitalWrite(ACTIVE_LED_PIN, on ? LOW : HIGH);
}

static void blink_status() {
    // Single short blink on status LED (won't block loop for long)
    digitalWrite(STATUS_LED_PIN, LOW);
    delay(12);
    digitalWrite(STATUS_LED_PIN, HIGH);
}

static void blink_error() {
    // Two rapid blinks to signal checksum error
    for (int i = 0; i < 2; i++) {
        digitalWrite(STATUS_LED_PIN, LOW);  delay(60);
        digitalWrite(STATUS_LED_PIN, HIGH); delay(60);
    }
}

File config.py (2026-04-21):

"""
HIDProxBox — Central configuration
Edit this file to match your hardware before running.
"""

from typing import Dict, List, Optional

# ── USB Gadget (optional legacy path — gadget_setup.sh) ──────────────────────
GADGET_NAME         = "hidproxbox"
GADGET_VENDOR_ID    = "0x1d6b"
GADGET_PRODUCT_ID   = "0x0104"
GADGET_MANUFACTURER = "VoyageTech"
GADGET_PRODUCT      = "HIDProxBox"
GADGET_SERIAL       = "HIDPX001"

HID_KEYBOARD_DEV    = "/dev/hidg0"
HID_MOUSE_DEV       = "/dev/hidg1"

# ── 4-Computer CH552T Serial Ports ───────────────────────────────────────────
# Each computer gets its own CH552T plugged into that computer's USB port.
# The Pi talks to all four CH552Ts over four USB-serial adapters.
#
# Wiring summary:
#   Pi /dev/ttyUSB0  TX/RX  ──►  CH552T #1  USB ──►  Computer 1
#   Pi /dev/ttyUSB1  TX/RX  ──►  CH552T #2  USB ──►  Computer 2
#   Pi /dev/ttyUSB2  TX/RX  ──►  CH552T #3  USB ──►  Computer 3
#   Pi /dev/ttyUSB3  TX/RX  ──►  CH552T #4  USB ──►  Computer 4

COMPUTERS: Dict[int, str] = {
    1: "/dev/ttyUSB0",
    2: "/dev/ttyUSB1",
    3: "/dev/ttyUSB2",
    4: "/dev/ttyUSB3",
}

SERIAL_BAUD         = 115200
SERIAL_TIMEOUT      = 0.1

# CH552T framing constants
CH552_FRAME_SOF     = 0xAA
CH552_TYPE_KBD      = 0x01
CH552_TYPE_MOUSE    = 0x02
CH552_TYPE_CONSUMER = 0x03
CH552_TYPE_SET_ACTIVE = 0x10   # payload: 0x01=active (LED on), 0x00=inactive
CH552_TYPE_RESET    = 0xFF

# ── Physical USB Keyboard Input ───────────────────────────────────────────────
# Set to "" to auto-detect the first keyboard in /dev/input/by-id/
# or set to a specific evdev path, e.g. "/dev/input/event2"
USB_KBD_DEVICE      = ""
USB_KBD_AUTO_DETECT = True

# ── Bluetooth — Keyboard Input (Pi as BT host) ────────────────────────────────
BT_INPUT_ENABLED    = True
BT_SCAN_TIMEOUT     = 10
BT_DEVICE_MAC       = ""        # lock to a specific keyboard MAC; "" = any
BT_AUTO_RECONNECT   = True
BT_RECONNECT_DELAY  = 5
BT_ADAPTER          = "hci0"
BT_HID_CONTROL_PSM  = 0x11
BT_HID_INTERRUPT_PSM = 0x13

# ── Bluetooth — Output (Pi as BT HID keyboard device) ────────────────────────
# When output_mode == "bluetooth", the Pi acts as a wireless keyboard
# to the selected computer.  Paired computer MACs are stored in this file
# so reconnect works across reboots.
BT_OUTPUT_ENABLED   = True
BT_OUTPUT_PAIRS_FILE = "/var/lib/hidproxbox/bt_output_pairs.json"
BT_OUTPUT_DEVICE_NAME = "HIDProxBox"
BT_PAIRING_TIMEOUT  = 60        # seconds discoverable while waiting to pair

# ── GPIO ─────────────────────────────────────────────────────────────────────
GPIO_ENABLED        = True
LONG_PRESS_S        = 1.5       # seconds held to trigger long-press action
GPIO_BOUNCE_MS      = 50

# Button map: BCM pin → { "short": action_name, "long": action_name }
# Actions are interpreted by GPIOWatcher and dispatched to the Router.
#
#   select_computer_N      — make computer N the active output target
#   input_bt               — switch keyboard input source to Bluetooth
#   input_usb              — switch keyboard input source to USB
#   pair_bt_keyboard       — enter BT pairing mode for the upstream keyboard
#   output_bt              — switch output for active computer to Bluetooth
#   output_usb             — switch output back to USB (CH552T)
#   pair_bt_output         — enter BT pairing mode (Pi as keyboard to computer)

BUTTON_MAP: Dict[int, Dict[str, str]] = {
    # ── Computer select ───────────────────────────────────────────────────────
    4:  {"short": "select_computer_1", "long": "select_computer_1"},
    17: {"short": "select_computer_2", "long": "select_computer_2"},
    27: {"short": "select_computer_3", "long": "select_computer_3"},
    22: {"short": "select_computer_4", "long": "select_computer_4"},

    # ── Keyboard input source ─────────────────────────────────────────────────
    # Short press: toggle USB ↔ BT keyboard input
    # Long press : enter BT pairing mode for the keyboard
    5:  {"short": "toggle_input",      "long": "pair_bt_keyboard"},

    # ── Computer output mode ──────────────────────────────────────────────────
    # Short press: toggle USB ↔ BT output for active computer
    # Long press : pair Pi as BT keyboard to active computer
    6:  {"short": "toggle_output",     "long": "pair_bt_output"},
}

# ── LED Pins (BCM numbering, optional — leave empty dict to disable) ──────────
# Active-high: HIGH = LED on.
LED_PINS: Dict[str, int] = {
    "computer_1": 12,
    "computer_2": 16,
    "computer_3": 20,
    "computer_4": 21,
    "input_bt":   24,   # lit when BT keyboard is the active input
    "output_bt":  25,   # lit when BT is the active output mode
}
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

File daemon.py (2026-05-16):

"""
daemon.py — HIDProxBox main daemon

Wires all subsystems together:

  Router          — central state machine + dispatch queue consumer
  HIDWriter       — 4× CH552T USB output (one per computer)
  BTOutput        — Pi as BT keyboard device (output to computers)
  BTListener      — BT keyboard input (upstream keyboard → Pi)
  USBKeyboard     — physical USB keyboard input via evdev
  GPIOWatcher     — buttons + LEDs

Data flow:
  USBKeyboard  ──┐
  BTListener   ──┼──► Router.report_queue ──► Router dispatch ──► HIDWriter  (USB out)
  GPIO macros  ──┘                                             └──► BTOutput  (BT out)

Usage
─────
  sudo python3 daemon.py [--foreground]

Systemd unit (example)
──────────────────────
  [Unit]
  Description=HIDProxBox
  After=network.target bluetooth.target

  [Service]
  Type=simple
  ExecStartPre=/usr/bin/bash /opt/hidproxbox/gadget_setup.sh up
  ExecStart=/usr/bin/python3 /opt/hidproxbox/daemon.py --foreground
  ExecStopPost=/usr/bin/bash /opt/hidproxbox/gadget_setup.sh down
  Restart=on-failure
  RestartSec=5

  [Install]
  WantedBy=multi-user.target
"""

import argparse
import logging
import logging.handlers
import os
import signal
import sys
import threading
import time

import config
from router import Router, InputMode, OutputMode, SOURCE_GPIO
from hid_writer import HIDWriter, ReportType
from gpio_watcher import GPIOWatcher
from bt_listener import BTListener
from bt_output import BTOutput
from usb_kbd import USBKeyboard


# ─────────────────────────────────────────────────────────────────────────────
# Logging
# ─────────────────────────────────────────────────────────────────────────────

def _setup_logging(foreground: bool) -> None:
    root = logging.getLogger()
    root.setLevel(getattr(logging, config.LOG_LEVEL, logging.INFO))
    fmt = logging.Formatter(
        "%(asctime)s  %(levelname)-8s  %(name)-16s  %(message)s",
        datefmt="%Y-%m-%d %H:%M:%S",
    )
    try:
        fh = logging.handlers.RotatingFileHandler(
            config.LOG_FILE,
            maxBytes=config.LOG_MAX_BYTES,
            backupCount=config.LOG_BACKUP_COUNT,
        )
        fh.setFormatter(fmt)
        root.addHandler(fh)
    except OSError as exc:
        print(f"[daemon] WARNING: cannot open log file: {exc}", file=sys.stderr)

    if foreground or config.LOG_TO_CONSOLE:
        sh = logging.StreamHandler(sys.stderr)
        sh.setFormatter(fmt)
        root.addHandler(sh)


# ─────────────────────────────────────────────────────────────────────────────
# PID file
# ─────────────────────────────────────────────────────────────────────────────

def _write_pid() -> None:
    try:
        with open(config.PID_FILE, "w") as f:
            f.write(str(os.getpid()))
    except OSError as exc:
        logging.getLogger(__name__).warning("Cannot write PID file: %s", exc)


def _remove_pid() -> None:
    try:
        os.remove(config.PID_FILE)
    except OSError:
        pass


# ─────────────────────────────────────────────────────────────────────────────
# Daemon
# ─────────────────────────────────────────────────────────────────────────────

class HIDProxDaemon:

    def __init__(self) -> None:
        self._log        = logging.getLogger("daemon")
        self._stop_event = threading.Event()

        # ── Core components ───────────────────────────────────────────────────
        self._router  = Router()
        self._writer  = HIDWriter()
        self._bt_out  = BTOutput()
        self._bt_in   = BTListener(self._router.report_queue)
        self._usb_kbd = USBKeyboard(self._router.report_queue)
        self._gpio    = GPIOWatcher(self._router)

        # Attach back-references so GPIOWatcher can trigger pairing operations
        self._router._bt_listener = self._bt_in
        self._router._bt_output   = self._bt_out

    # ── entry point ───────────────────────────────────────────────────────────

    def run(self) -> int:
        self._log.info("=" * 64)
        self._log.info("HIDProxBox starting  (pid %d)", os.getpid())
        self._log.info("  Computers : %s", list(config.COMPUTERS.keys()))
        self._log.info("  Buttons   : %d configured", len(config.BUTTON_MAP))
        self._log.info("  LEDs      : %d configured", len(config.LED_PINS))
        self._log.info("=" * 64)

        _write_pid()
        self._install_signals()
        self._start_all()

        code = self._watchdog_loop()

        self._stop_all()
        _remove_pid()
        self._log.info("HIDProxBox exited (code %d).", code)
        return code

    # ── signal handling ───────────────────────────────────────────────────────

    def _install_signals(self) -> None:
        for sig in (signal.SIGTERM, signal.SIGINT):
            signal.signal(sig, self._handle_signal)
        signal.signal(signal.SIGHUP, lambda *_: self._log.info("SIGHUP — reload not implemented."))

    def _handle_signal(self, signum: int, _frame) -> None:
        self._log.info("Signal %s received — shutting down.", signal.Signals(signum).name)
        self._stop_event.set()

    # ── router wiring ─────────────────────────────────────────────────────────

    def _wire_router(self, router: Router) -> None:
        """
        Attach all sinks, back-references, and callbacks to a Router instance.
        Called from both _start_all() and the watchdog restart block so that
        a restarted Router is fully wired identically to the original.
        """
        # Output sinks
        router.set_usb_sink(self._writer.write)
        router.set_bt_sink(self._bt_out.send)

        # Back-references so GPIOWatcher can trigger BT pairing after restart
        router._bt_listener = self._bt_in
        router._bt_output   = self._bt_out

        # State-change hook: keep BTOutput slot in sync + GPIO LED updates
        gpio = self._gpio

        def _notify_with_bt(*args, **kwargs):
            router._orig_notify(*args, **kwargs)
            computer, _, out_mode = router.snapshot()
            if out_mode == OutputMode.BLUETOOTH:
                self._bt_out.set_active_slot(computer)

        router._orig_notify = router._notify
        router._notify      = _notify_with_bt

        # GPIO state-change callback for LED updates
        router.set_on_state_change(gpio._on_state_change)

    # ── startup ───────────────────────────────────────────────────────────────

    def _start_all(self) -> None:
        # 1. Open CH552T serial ports
        self._log.info("Opening CH552T serial links…")
        self._writer.open()

        # 2. Wire Router sinks, back-references, and callbacks
        self._wire_router(self._router)

        # 3. Start threads (order: router first, then sources, then GPIO)
        self._log.info("Starting Router…")
        self._router.start()

        self._log.info("Starting BTOutput…")
        self._bt_out.start()

        self._log.info("Starting BTListener (keyboard input)…")
        self._bt_in.start()
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

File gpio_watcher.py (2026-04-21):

"""
gpio_watcher.py — Physical button watcher with short/long press detection

Monitors all buttons defined in config.BUTTON_MAP.  Each button supports:
  • Short press  (< LONG_PRESS_S):  fires "short" action
  • Long press   (≥ LONG_PRESS_S):  fires "long"  action

All buttons are active-low (press pulls pin to GND via momentary switch;
internal pull-up keeps pin HIGH at rest).

Button layout (BCM pins, from config.py)
─────────────────────────────────────────
  Pin  4  — Computer 1  (short & long)
  Pin 17  — Computer 2  (short & long)
  Pin 27  — Computer 3  (short & long)
  Pin 22  — Computer 4  (short & long)
  Pin  5  — BT keyboard  short=toggle USB↔BT input   long=pair BT keyboard
  Pin  6  — BT output    short=toggle USB↔BT output   long=pair Pi to computer

LED feedback
─────────────
  GPIOWatcher subscribes to Router.set_on_state_change() so it can
  update the indicator LEDs immediately whenever routing state changes.

Long-press approach
────────────────────
  We use RPi.GPIO BOTH-edge detection.
  FALLING  → record press_start time for that pin.
  RISING   → compute duration; dispatch short or long action.
"""

import logging
import time
import threading
from typing import Dict, Optional

import config

log = logging.getLogger(__name__)


# ─────────────────────────────────────────────────────────────────────────────

class GPIOWatcher(threading.Thread):

    def __init__(self, router) -> None:
        """
        router : router.Router instance
        """
        super().__init__(name="gpio-watcher", daemon=True)
        self._router     = router
        self._stop       = threading.Event()
        self._gpio       = None
        self._press_time : Dict[int, float] = {}   # pin → press start monotonic time
        self._press_lock = threading.Lock()

    # ── lifecycle ─────────────────────────────────────────────────────────────

    def start(self) -> None:
        if not config.GPIO_ENABLED:
            log.info("GPIOWatcher disabled in config.")
            return
        try:
            import RPi.GPIO as GPIO
            self._gpio = GPIO
        except (ImportError, RuntimeError) as exc:
            log.warning("RPi.GPIO unavailable: %s — GPIO watcher disabled.", exc)
            return

        self._setup_gpio()

        # Subscribe to state changes so we can update LEDs
        self._router.set_on_state_change(self._on_state_change)

        super().start()
        log.info("GPIOWatcher started; %d button(s) active.", len(config.BUTTON_MAP))

        # Initial LED state
        self._on_state_change(*self._router.snapshot())

    def stop(self) -> None:
        self._stop.set()
        self.join(timeout=3)
        if self._gpio:
            try:
                self._gpio.cleanup()
            except Exception:
                pass
        log.info("GPIOWatcher stopped.")

    # ── main loop ─────────────────────────────────────────────────────────────

    def run(self) -> None:
        # Callbacks fire in RPi.GPIO's internal thread.
        # This thread just keeps the watcher alive and handles long-press
        # timeouts (fires the long-press action while button is still held).
        while not self._stop.is_set():
            now = time.monotonic()
            with self._press_lock:
                for pin, start_t in list(self._press_time.items()):
                    held = now - start_t
                    if held >= config.LONG_PRESS_S:
                        # Fire long press now (don't wait for release) and
                        # remove from tracking so we don't fire again.
                        del self._press_time[pin]
                        threading.Thread(
                            target=self._fire_action,
                            args=(pin, "long"),
                            daemon=True,
                        ).start()
            time.sleep(0.05)   # 50 ms poll

    # ── GPIO setup ────────────────────────────────────────────────────────────

    def _setup_gpio(self) -> None:
        GPIO = self._gpio
        GPIO.setmode(GPIO.BCM)
        GPIO.setwarnings(False)

        # ── Button pins ───────────────────────────────────────────────────────
        for pin in config.BUTTON_MAP:
            GPIO.setup(pin, GPIO.IN, pull_up_down=GPIO.PUD_UP)

            def _make_cb(p):
                def _cb(channel):
                    self._button_event(p)
                return _cb

            GPIO.add_event_detect(
                pin,
                GPIO.BOTH,
                callback=_make_cb(pin),
                bouncetime=config.GPIO_BOUNCE_MS,
            )
            log.debug("GPIO button pin %d registered.", pin)

        # ── LED pins ──────────────────────────────────────────────────────────
        for name, pin in config.LED_PINS.items():
            GPIO.setup(pin, GPIO.OUT, initial=GPIO.LOW)
            log.debug("GPIO LED '%s' on pin %d.", name, pin)
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

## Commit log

2026-03-30 Initial commit — HIDProxBox 4-port KVM with BT input/output
    - config.py: 4-computer serial map, 6-button layout (short/long press), LED pins
    - router.py: central state machine (active computer, input/output mode)
    - hid_writer.py: multi-computer CH552T USB sink with active-LED sync
    - gpio_watcher.py: short/long press detection, computer select, BT pair buttons
    - bt_listener.py: BT HID host (Pi receives from BT keyboard)
    - bt_output.py: BT HID device (Pi appears as keyboard to computers)
    - usb_kbd.py: evdev USB keyboard reader
    - daemon.py: orchestrates all subsystems
    - firmware/ch552t_hid_proxy.ino: CH552T USB HID proxy with active-LED command
    [bt_listener.py, bt_output.py, ch552t_hid_proxy.ino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]
2026-03-30 Add README — purpose, architecture, wiring, install, and operation
2026-04-21 docs: rewrite README with full setup, wiring diagrams, web UI, display, and troubleshooting
    - Add web_ui.py and display.py documentation (both missing from prior README)
    - Expand Assembly & Wiring with overview diagram and per-unit CH552T wiring blocks
    - Add CH552T serial frame protocol reference and LED behavior table
    - Add HID Macros section with modifier byte reference
    - Add Troubleshooting section (serial, BT, web UI, display, GPIO, dropped keys)
    - Add Table of Contents and ZSA Keymapp integration docs
    - Fix systemd service example to include gadget_setup.sh pre/post hooks
    - Update Project Structure table with web_ui.py and display.py entries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
2026-04-21 docs: add web UI and local display screenshots to README
    Screenshots taken from live running instances:
    - docs/screenshot-web-ui.png — browser control panel at :8080 (Computer 1 active, USB input/output)
    - docs/screenshot-display.png — display.py tkinter GUI showing tally buttons, input/output modes, and Keymapp launcher
    Both images embedded in their respective README sections.
2026-04-21 feat: add GitHub Pages marketing site and brand assets
    Static HTML/CSS landing page deployable from docs/ with:
    - Hero, feature highlights, use-case scenarios, BOM table, get-started
    - Dark-mode-first design with light mode via prefers-color-scheme
    - Mobile-responsive layout
    - Open Graph and Twitter Card meta tags
    - Brand SVGs (logos, icon, social preview) in docs/assets/
2026-04-21 branding: add web design system, CSS tokens, and component mockups
    - tokens.css: full CSS custom property set for colors, typography, spacing,
    shadows, transitions, and dark/light mode; utility classes for badge, card,
    and button components
    - web-design-system.md: developer handoff spec covering all tokens, component
    anatomy, breakpoints, accessibility contrast ratios, and mode-switching logic
    - mockup-hero.svg: nav bar + hero section with logo, tagline, CTA buttons,
    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
2026-04-21 feat: align marketing site with DVI-27 design system
    - Import branding/tokens.css (copied to docs/tokens.css) as source of truth
    - Switch light mode to data-theme="light" + localStorage toggle button in nav
    - Hero: centered layout with large logo, tagline below, three badge pills
    - Feature cards: top accent strip + leading dot + INPUT/OUTPUT category label
    matching design system spec (4 cyan INPUT, 4 blue OUTPUT)
    - Use-case cards: category badge pill + callout row with accent dot
    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
2026-04-21 feat(branding): add enclosure design concepts for DVI-33
    Three SVG mockups presenting enclosure options for board approval:
    - Option A: Compact Slab (175×90×32mm, horizontal KVM style)
    - Option B: Desktop Puck (100×100×95mm, upright tower — recommended)
    - Option C: Control Deck (220×120×22mm, ultra-thin angled surface)
    - Overview comparison with recommendation and print feasibility notes
    Each design accommodates: 3.5" touchscreen, 4 computer select buttons,
    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
2026-04-21 feat(hardware): add parametric enclosure CAD and STL for Option A slab (DVI-35)
    - enclosure.scad: fully parametric OpenSCAD model (175×90×32 mm)
    two-piece shell (bottom tray + top lid), M3 heat-set inserts,
    alignment rib, front/back/vent cutouts matching approved DVI-33 concept
    - generate_stl.py: headless STL generator via manifold3d + numpy-stl
    - stl/enclosure_bottom.stl: main tray (1,788 tris, 87 KB)
    - stl/enclosure_top_lid.stl: flat cover (828 tris, 40 KB)
    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
    [enclosure.scad, enclosure_bottom.stl, enclosure_top_lid.stl]
2026-04-21 feat(hardware): add desktop v2 and handheld enclosure designs (DVI-38)
    - enclosure_desktop_v2.scad: enhanced desktop slab with 3° ergonomic tilt,
    dual-side chevron vent slots, rubber-foot recesses, logo plate recess on
    lid, and interior cable-clip boss; same 175×90mm footprint / port layout
    - enclosure_handheld.scad: new 120×62×22mm candy-bar for Pi Zero 2W +
    2×CH552T; bottom-exit USB ports, right-side USB-C power, grip ridges,
    1.3" OLED opening, M2.5 bosses
    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
    [enclosure_desktop_v2.scad, enclosure_handheld.scad]
2026-04-21 feat(hardware): update handheld enclosure to DVI-39 constraint spec
    Redesign enclosure_handheld.scad to comply with the hardware constraint
    spec delivered in DVI-39:
    - Footprint reduced from 120×62 mm to 90×50 mm (meets ≤90×50 mm target)
    - Height increased from 22 mm to 30 mm to fit 4× CH552T on 10 mm standoffs
    - Select buttons increased from 2 to 4 (two paired groups: C1+C2 / C3+C4)
    - Status LEDs increased from 2 to 4 (3 mm dia, one per computer)
    - USB-A outputs increased from 2 (bottom-exit) to 4 (back-panel, 15 mm pitch)
    - USB-A keyboard input moved to back panel (aligns with 5-port back cluster)
    - Battery placeholder void added (SHOW_BATTERY_VOID flag; chemistry TBD)
    - Display ope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
    [enclosure_handheld.scad]
2026-04-21 feat(hardware): add handheld enclosure STL exports (DVI-38)
    Generated from enclosure_handheld.scad rev 2 (90×50×30 mm, 4-computer):
    - handheld_bottom.stl 675 facets, manifold
    - handheld_top.stl 256 facets, manifold
    Also fix syntax error in x_rounded_rect_cutter (unused helper module
    had invalid OpenSCAD variable assignment syntax — removed).
    [enclosure_handheld.scad, handheld_bottom.stl, handheld_top.stl]
2026-04-21 feat(web_ui): add paste-text-to-keystrokes feature (DVI-41)
    - Add POST /api/paste endpoint — accepts JSON {"text":"…"}, validates
    length (max 2000 chars), delegates to router.type_text(text)
    - Add CHAR_MAP module constant: US ANSI HID keycode table mapping 95
    printable characters (letters, digits, shifted symbols, punctuation,
    whitespace) to (keycode, modifier) pairs per USB HID Usage Tables 1.21
    - Add PASTE_TEXT_LIMIT = 2000 safety cap to avoid saturating the serial pipeline
    - Add _Handler._read_json_body() helper for Content-Length-framed JSON bodies
    - Add Paste Text card to the embedded HTML: monospace textarea, Send as
    Keystrokes button with disabled/sending states, inline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
    [web_ui.py]
2026-04-21 docs(dvi-42): document paste text entry feature in README and GitHub Pages site
    - Add Paste Text Entry section to README Web Control Panel chapter,
    explaining how to use the browser paste box to send complex text and
    passwords to the active computer as HID keystrokes
    - Document the new POST /api/paste endpoint with request format and
    curl example
    - Add Paste Text Entry feature card to docs/index.html Feature
    Highlights grid
    - Add "Password Problem" use-case card to the Who It's For section
2026-04-21 docs(dvi-42): correct paste docs against DVI-41 implementation
    - Endpoint returns {"sent": N, "skipped": N} not status JSON — fix
    README table description and API usage example accordingly
    - Add 2000-char limit to endpoint table, prose, and curl example
    - Button label corrected to "Send as Keystrokes"
    - Note that non-US-ANSI characters are skipped and counted
    - Update docs/index.html feature card with accurate send limit and
    button label
2026-04-21 docs(dvi-43): update web UI screenshot and add web panel section to marketing site
    - Replace screenshot-web-ui.png with full-page render showing the Paste Text
    card (the prior screenshot was taken before DVI-41 added that feature)
    - Add Web Control Panel section to GitHub Pages site with screenshot, Paste
    Text feature callout, use-case list, and API reference block
    - Add supporting CSS for the web-ui-showcase layout
2026-05-15 fix: bt_listener — BT_ENABLED -> BT_INPUT_ENABLED, add SOURCE_BT to queue tuple
    DVI-9: config.BT_ENABLED did not exist; daemon crashed with AttributeError on
    boot. Updated BTListener.start() to check config.BT_INPUT_ENABLED which is the
    correct config key defined in config.py.
    DVI-10: _receive_loop pushed 2-tuple (report_type, payload) to the shared queue
    but Router._dispatch() unpacks a 3-tuple (source, report_type, data). Added
    import of SOURCE_BT from router and prepended it to the put_nowait call so BT
    keyboard reports are routed correctly instead of raising ValueError.
    [bt_listener.py]
2026-05-16 fix: DVI-11/12/14/15 — stuck keys, consumer reports, watchdog wiring, mouse passthrough
    DVI-11: router.py select_computer() now sends null keyboard+mouse reports to
    the old computer (via _release_old_computer()) before switching, preventing
    stuck keys when switching with a key held down.
    DVI-12: bt_listener.py _classify() now returns ReportType.CONSUMER for 2-byte
    and 3-byte payloads, so volume/media key reports from BT keyboards are
    forwarded instead of being silently dropped as 'unclassified'.
    DVI-14: daemon.py extracts _wire_router() helper that attaches sinks,
    _bt_listener/_bt_output back-references, and the notify/state-change hooks.
    Both _start_all() and the watchdog restart block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
    [bt_listener.py, daemon.py, router.py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]
